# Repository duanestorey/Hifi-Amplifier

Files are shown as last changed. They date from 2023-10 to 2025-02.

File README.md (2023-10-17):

# Hifi-Amplifier
A Custom 5.1 LM3886 Based Custom Amplifier.  The LM3886 has a somewhat mythical status ever since a $3,000 gaincard was released in 1999.  It had amazing sound quality, but inside was only a tweaked LM3886 Texas Instrument 68W amplifier IC.  Since then, an entire community has evolved around these 'gainclones', which truly are hi-fidelity.  This project uses 5 of these, along with a Dolby Decoder IC, to create a complete DIY hi-fidelity 5.1 system.

A breakdown of the directory structure is as follows:

* PCBs - Each of the required PCBs in detail
* Code/ESP32 - The main amplifier code, written to run on an ESP32 WROOM 32 processor  - currently a work in progress and incomplete as the code has recently been changed from a STM32

# Design Philosophy

## PCBs

After iterations over several months to determine PCB usefulness and sizes, most PCBs now utilize a 55mmx55mm size.  This is under the minimum of 100mmx100mm low-cost options 
at several of the large-scale PCB manufacturing sites, and allows useful stacking of PCBs within the chassis.

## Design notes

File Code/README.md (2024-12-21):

### Code

The primary code for the amplifier uses the Espressif IDF framework for the ESP32 chip. 

The DSP routines were coded using the CubeIDE and framework for the STM32 devices.

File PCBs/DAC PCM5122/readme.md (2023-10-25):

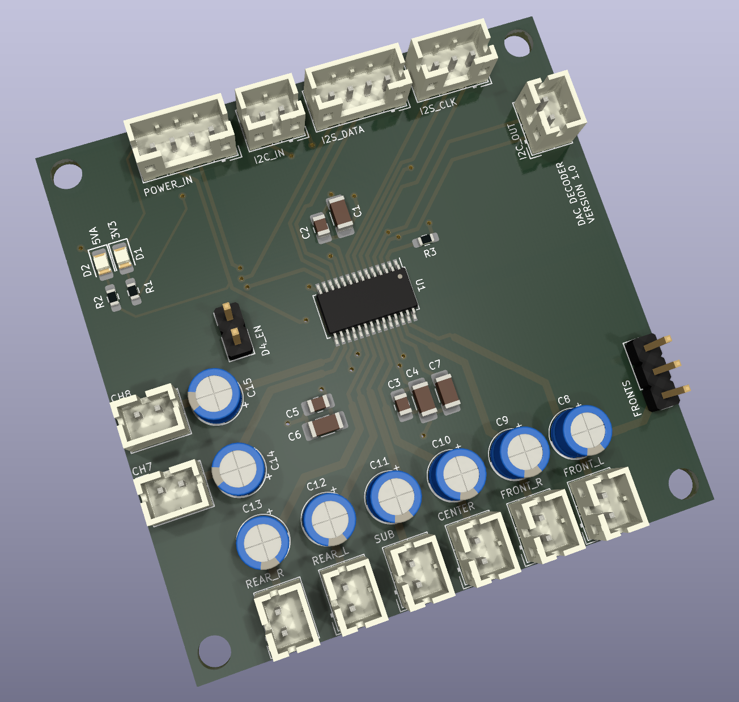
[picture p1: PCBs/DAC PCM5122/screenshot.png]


# Digital To Analog Converter

This PCB is based on the 8 channel Burr Brown PCM1681 IC.  It converts the I2S streams from the Dolby Digital Decoder PCB into 5.1 channel audio for the amplifier.

## Power Connections

### Input 

1. 4-pin GND, 3V3, AGND, 5VA digital/analog

## Version History

- 1.0: Initial Release
- 1.1: Improved Routing

## To Do:

- 1.2: 
    * Add missing address selection pin
    * Impedence match I2S lines

## Speciality Components

* PCM1681 Burr Brown DAC
* Nichicon Muse ES 25V 10uF bi-polar capacitors

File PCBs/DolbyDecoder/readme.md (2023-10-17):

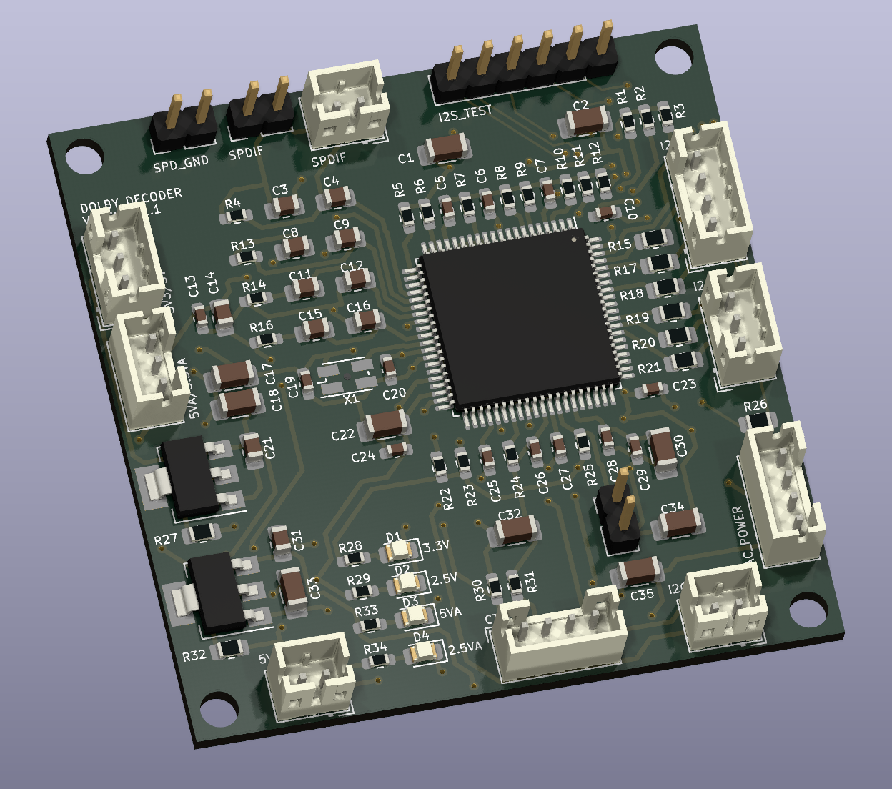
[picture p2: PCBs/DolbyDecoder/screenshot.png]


# Dolby Digital Decoder

This PCB decodes a SPDIF Dolby Digital 5.1 or PCM stream.  It is based on the STA310 set-top box Dolby Digital Decoding IC.

## Speciality Components

* STA310 Dolby Digital Decoding IC
* 27 MHz Clock
* 2.5V 3-pin regulators

## Power Connections

### Input 

1. 3-pin GND, 3V3, 5V digital
2. 3-pin AGND, 3V3A, 5VA analog

### Output

1. 2-pin GND, 5V digital
2. 4-pin GND, 3V3, AGND, 5VA combined digital/analog

## Version History

- 1.0: 
    * Initial Release
- 1.1: 
    * Routed I2S_D0 from Dolby Digital (which is two channel Dolby) to the DAC I2S_D4 pin
    * Re-annotated geographically

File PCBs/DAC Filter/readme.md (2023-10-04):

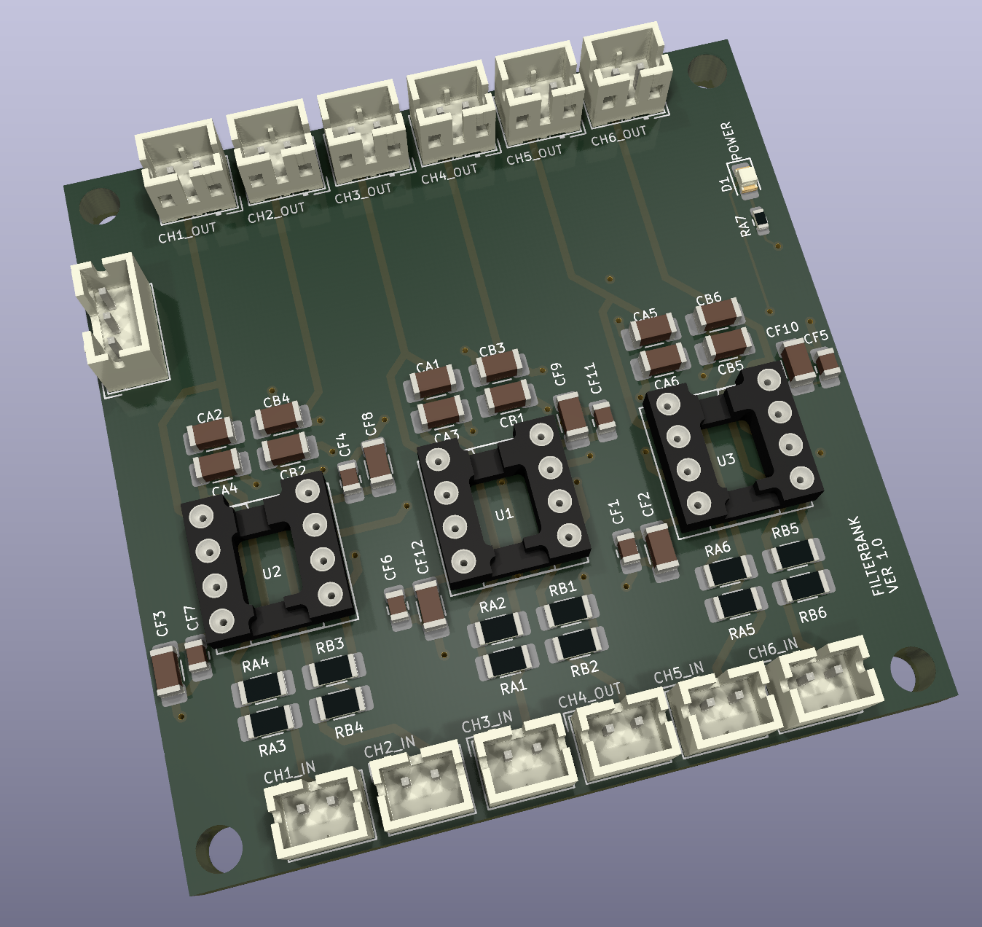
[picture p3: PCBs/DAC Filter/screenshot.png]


# DAC Filters

The output from the DAC board contains some residual noise that needs to be filtered out, which is the purpose of this board.  It utilizes three dual op-amps 
set up as active filters, one for each channel. 

## Power Connections

### Input 

1. 3-pin V-, AGND, V+

## Version History

- 1.0: Initial Release

## Speciality Components

* OPA2134 Burr Brown operation op-amps or equivalents
* 300pF and 30pF C0G 1206 capacitors
* 7.5K and 130K thin film 1206 capacitors

## Filter Design

Texas Instruments recommends a simple first order active Sallen Key filter to reduce the level of post-DAC noise in the audio stream.

I used an online filter designer, setting a 0.2dB drop at 24kHz, with a stopband of -11.5dB at 100kHz.  These were chosen iteratively to try and keep the passband
relatively flat, and the gain as large as possible while still being a second order filter.  The final design has a 3dB corner frequency of 53.7kHz.

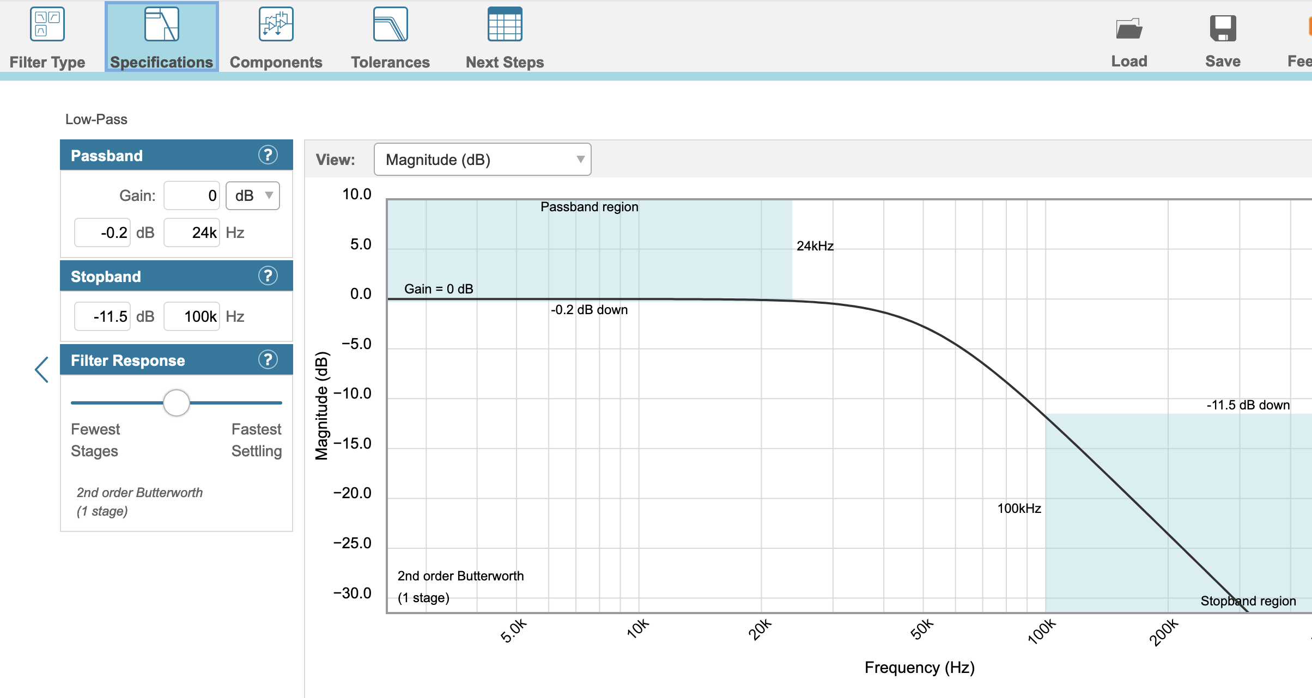
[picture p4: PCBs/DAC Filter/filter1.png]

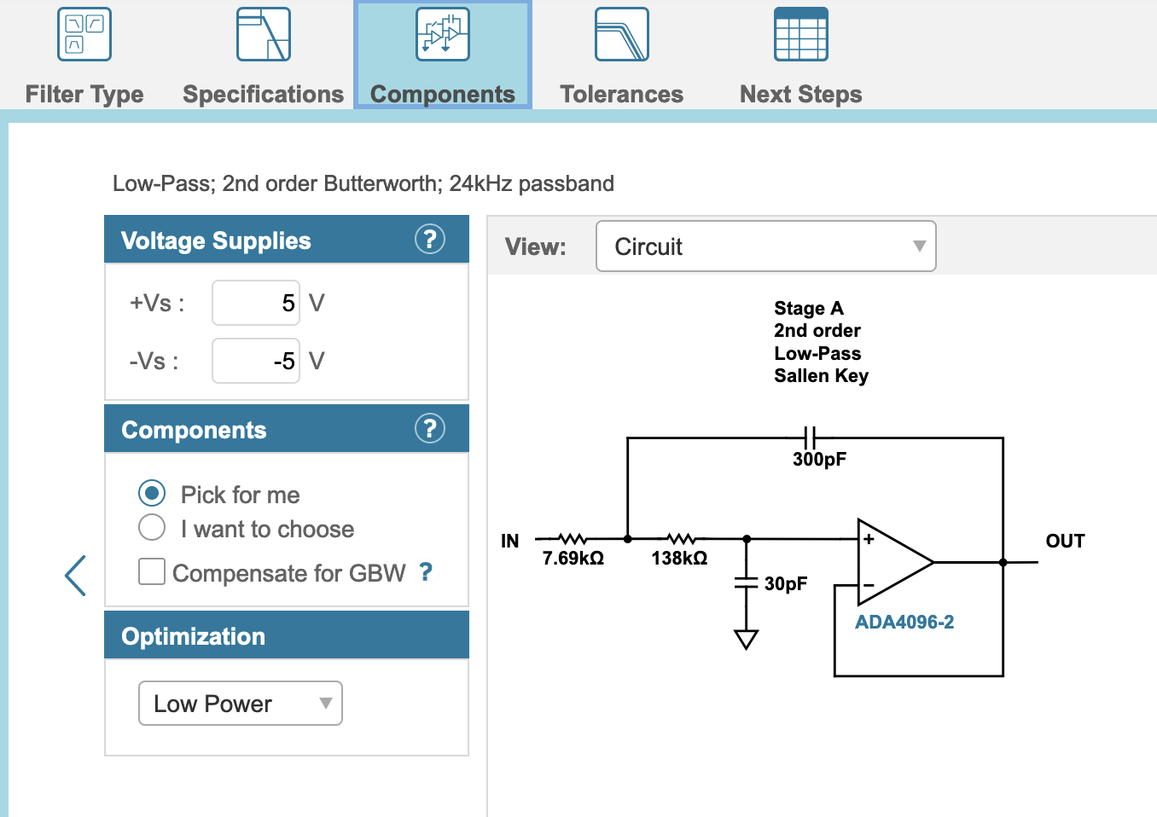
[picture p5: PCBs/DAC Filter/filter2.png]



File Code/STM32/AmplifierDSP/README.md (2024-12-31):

## DSP Code

This code is for a four channel digital signal processor for my Hi-Fi Amplifier.  It will process one stereo input channel and create three 
separate I2S digital audio output channels after processing each using biquad filters.

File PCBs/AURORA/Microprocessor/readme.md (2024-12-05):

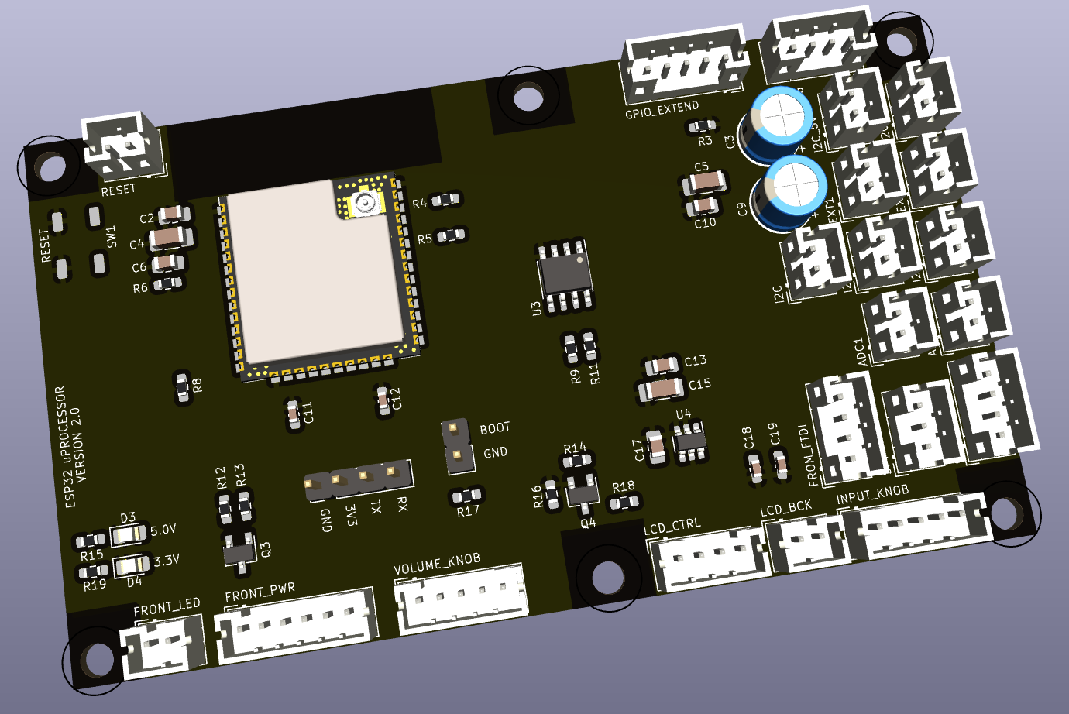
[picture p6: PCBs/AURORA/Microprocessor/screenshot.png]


# Microprocessor Board

The heart of the amplifier is this microprocessor board based on the ESP32 WROOM 32 IC. Now supports a HAT.

## Version History

- 1.0: Initial Release
- 1.1: Addressed issue with ESP32 programming transistors
- 1.2: Added missing pull-down resistor for relay/softstart 

## Speciality Components

* ESP32 WROOM 32
* FT232RL USB to UART converter
* TMP100 temperature sensor

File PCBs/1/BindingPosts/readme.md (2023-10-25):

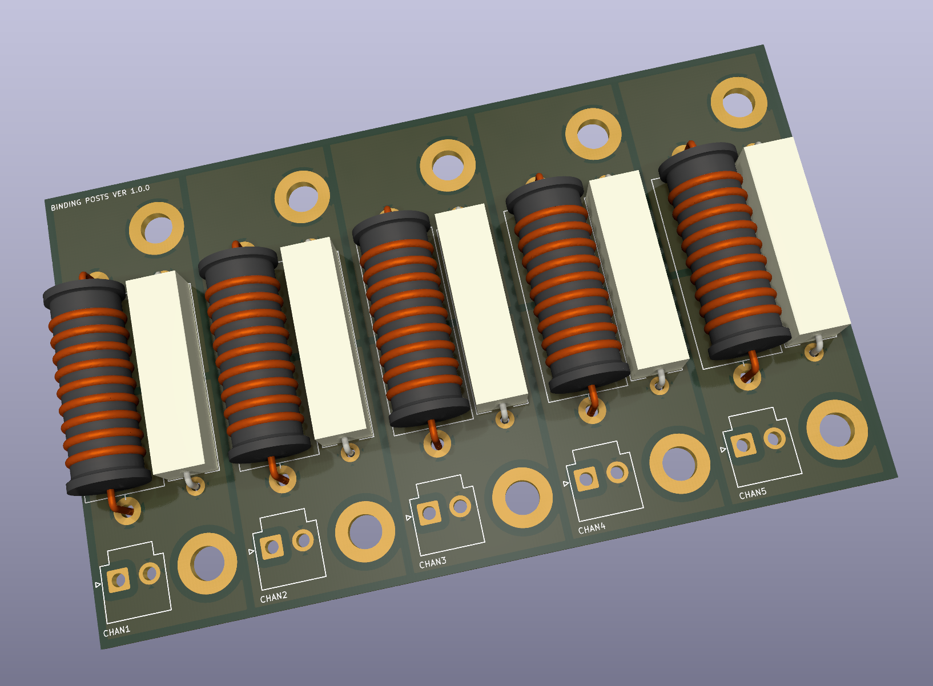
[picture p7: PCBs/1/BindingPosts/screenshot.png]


# Binding Posts

## Version History

- 1.0: Initial Release
- 1.1: First attempt at speaker protection relays

## Speciality Components

* 0.7uH air-core hand-wound inductors
* 5W resistors

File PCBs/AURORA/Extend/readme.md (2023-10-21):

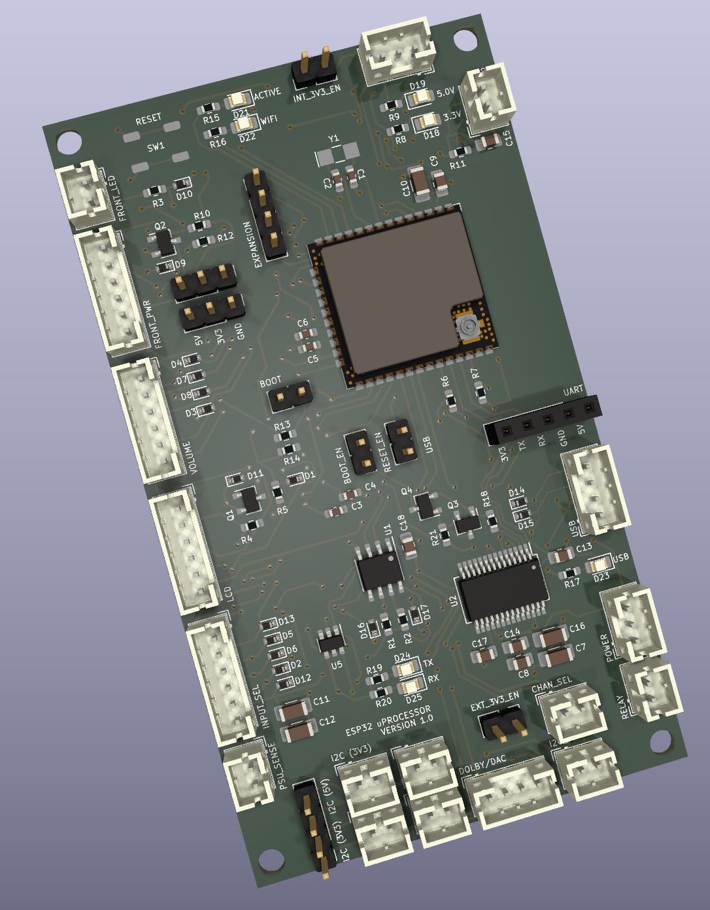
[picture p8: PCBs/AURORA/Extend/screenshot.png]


# Microprocessor Board

The heart of the amplifier is this microprocessor board based on the ESP32 WROOM 32 IC.

## Version History

- 1.0: Initial Release
- 1.1: Addressed issue with ESP32 programming transistors
- 1.2: Added missing pull-down resistor for relay/softstart 

## Speciality Components

* ESP32 WROOM 32
* FT232RL USB to UART converter
* TMP100 temperature sensor

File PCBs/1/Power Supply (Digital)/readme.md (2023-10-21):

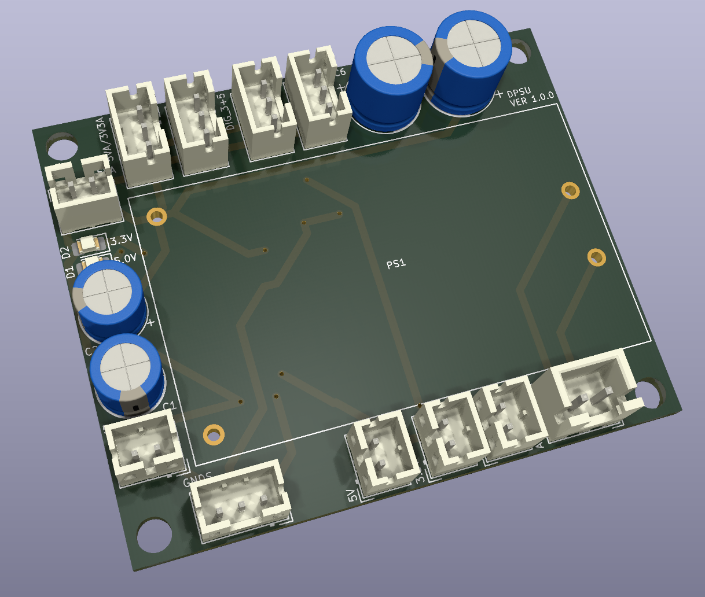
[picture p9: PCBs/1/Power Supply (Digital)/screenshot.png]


# Digital Power Supply

## Version History

- 1.0: Initial Release
- 1.1: Reduced capacitance, added additional connectors

## Speciality Components

* HLK-10M05 5V 10W power supply
* 3.3V regulator

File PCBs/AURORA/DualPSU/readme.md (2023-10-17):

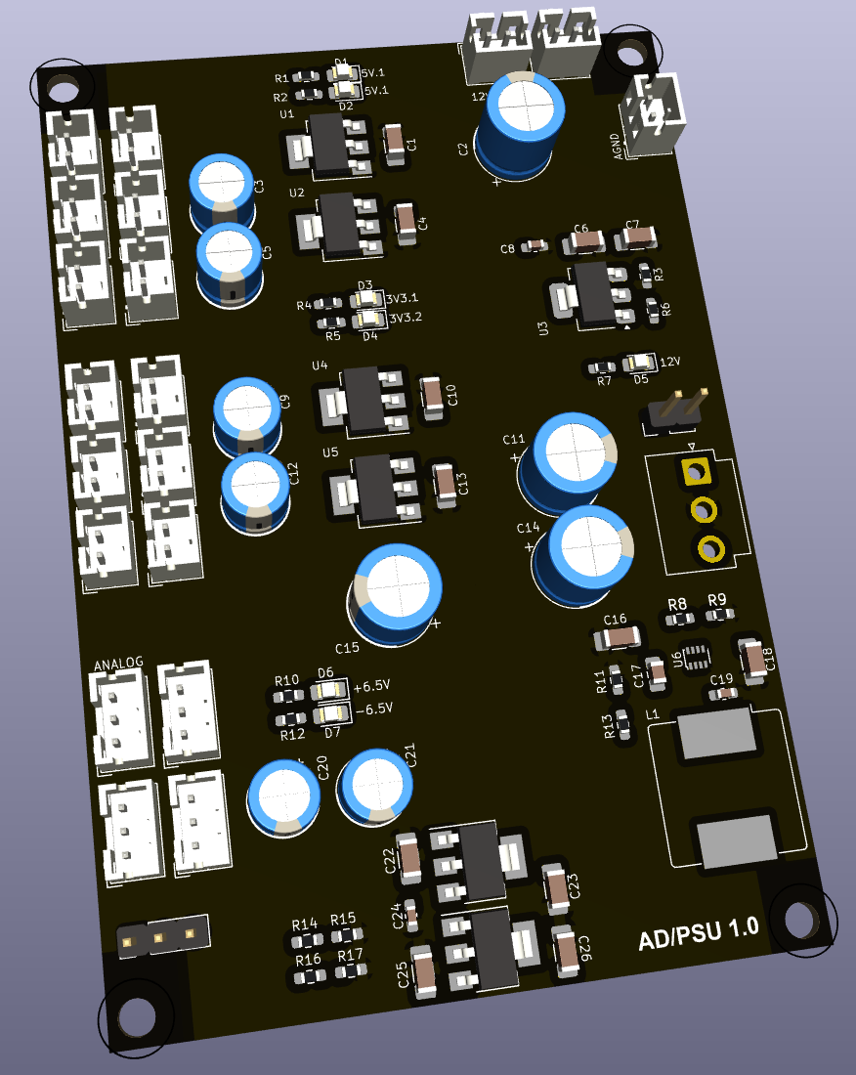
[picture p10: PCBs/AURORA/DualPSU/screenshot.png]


# Analog Power Supply for Operation Amplifier

This board produces a +/- 6.5V supply to be used with the DAC filter and the phono RIAA/pre-amplifier PCBs

## Version History

- 1.0: Initial Release

## Speciality Components

* LM317 & LM337 variable voltage regulators
* Myrra 44091 1.5VA with dual 6V secondaries

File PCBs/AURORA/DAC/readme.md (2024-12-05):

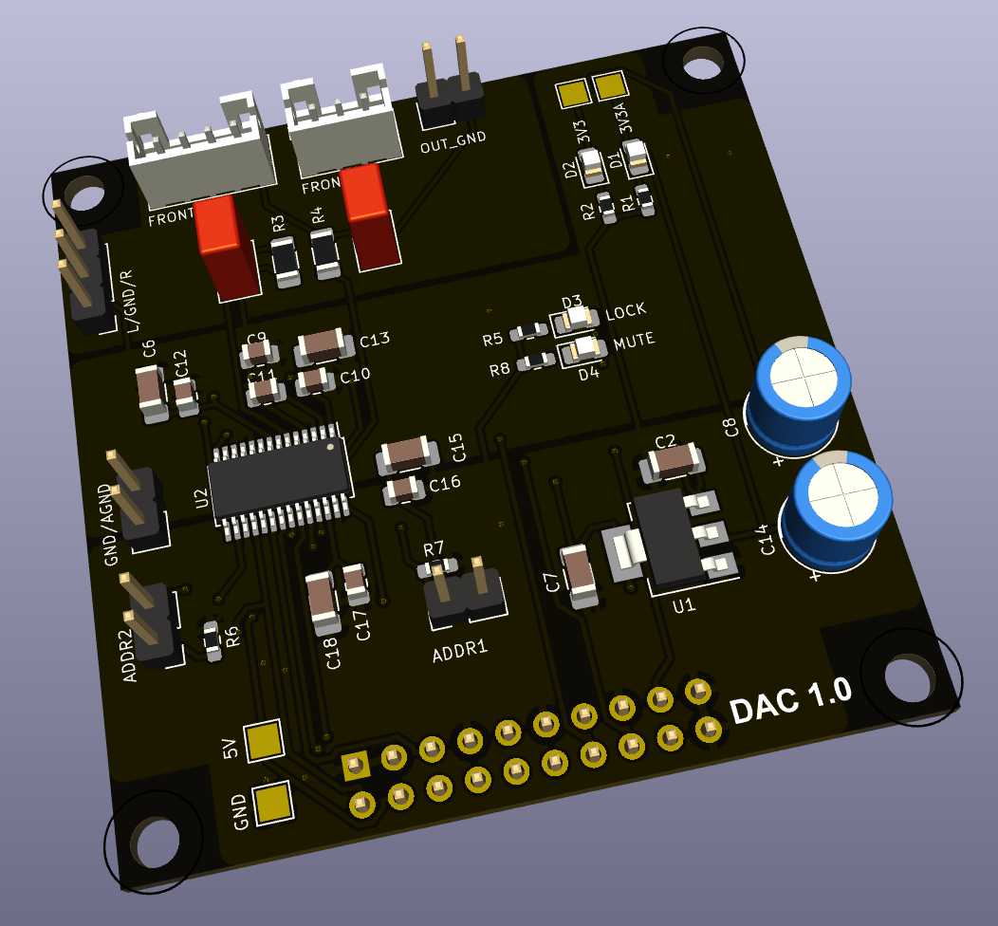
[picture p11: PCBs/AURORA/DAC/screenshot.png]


## DAC 

### Version History

- 1.0: Initial Release

## #Speciality Components

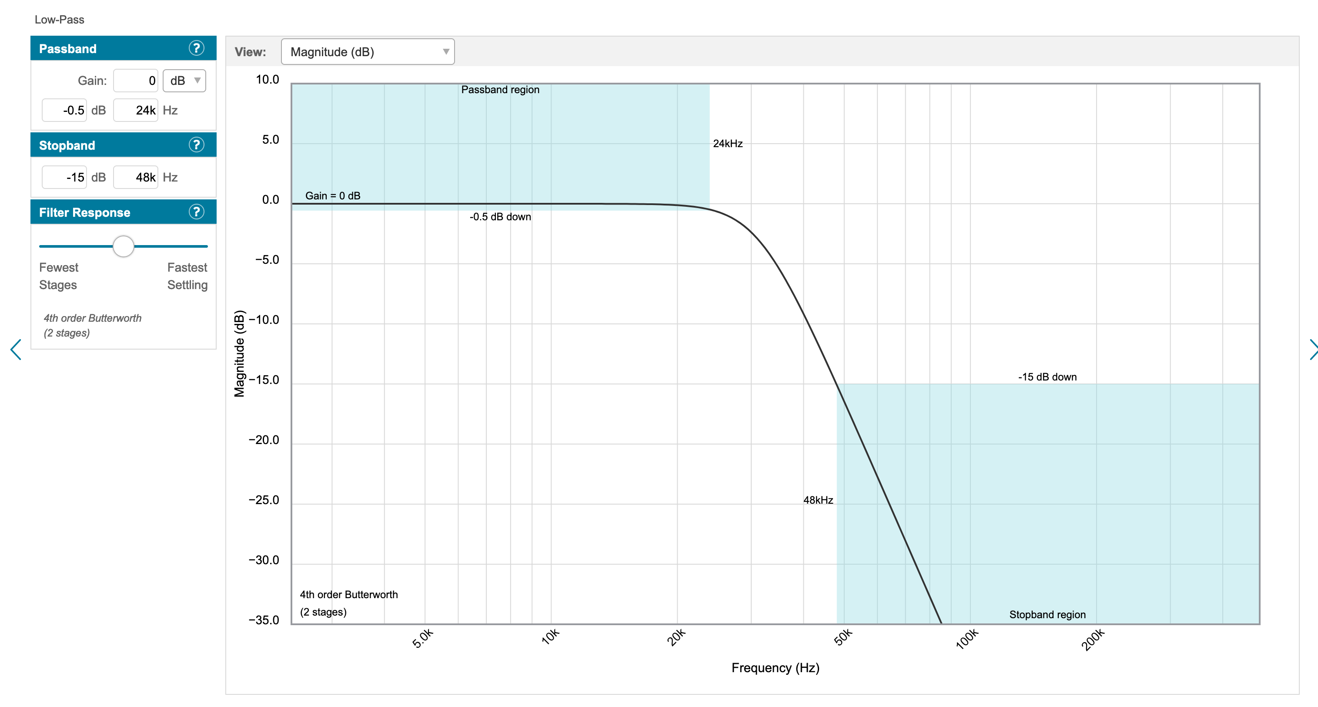
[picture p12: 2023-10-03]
PCBs/DAC Filter/1.1/Filter Design/Screenshot 2023-09-28 at 11.56.09 AM.png

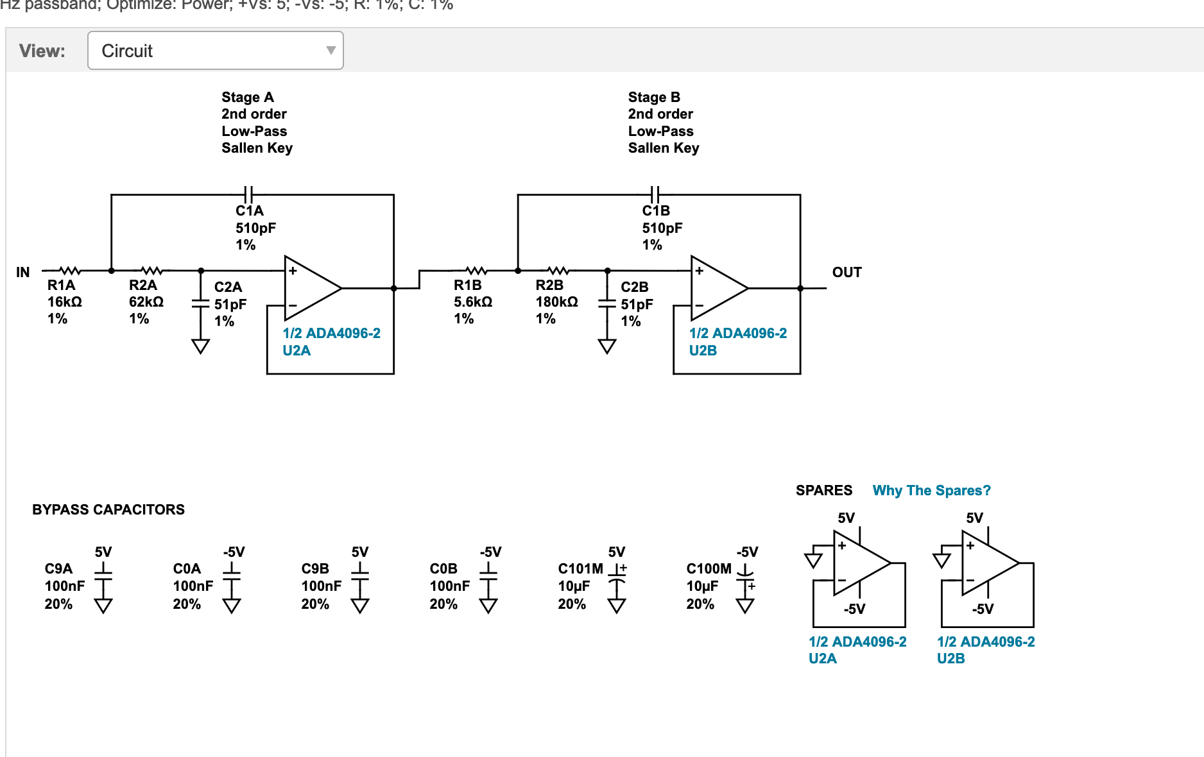
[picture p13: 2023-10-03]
PCBs/DAC Filter/1.1/Filter Design/Screenshot 2023-09-28 at 11.56.31 AM.png

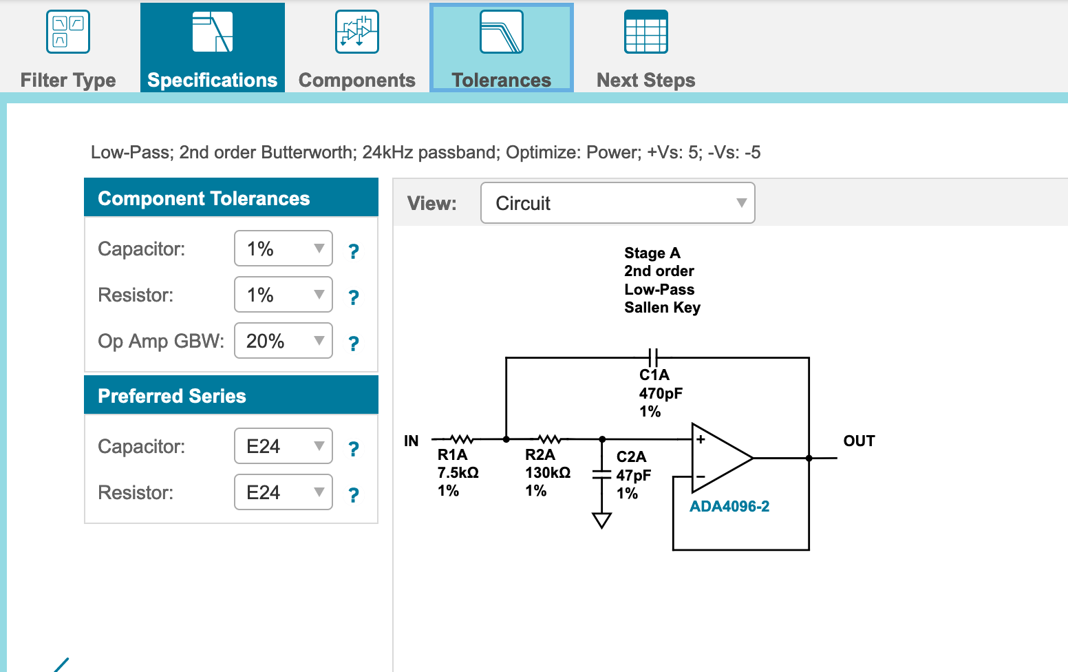
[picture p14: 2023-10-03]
PCBs/DAC Filter/1.1/Filter Design/filter3.png

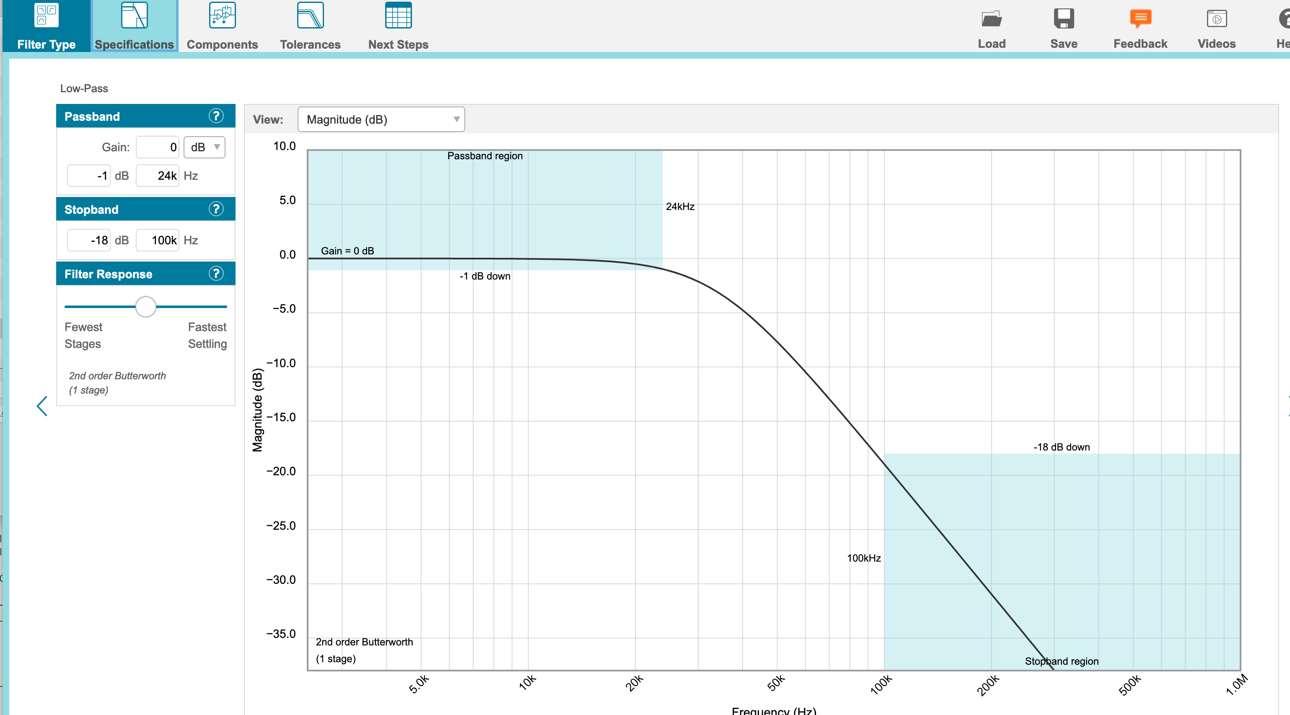
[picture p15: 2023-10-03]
PCBs/DAC Filter/1.1/Filter Design/filter1.png

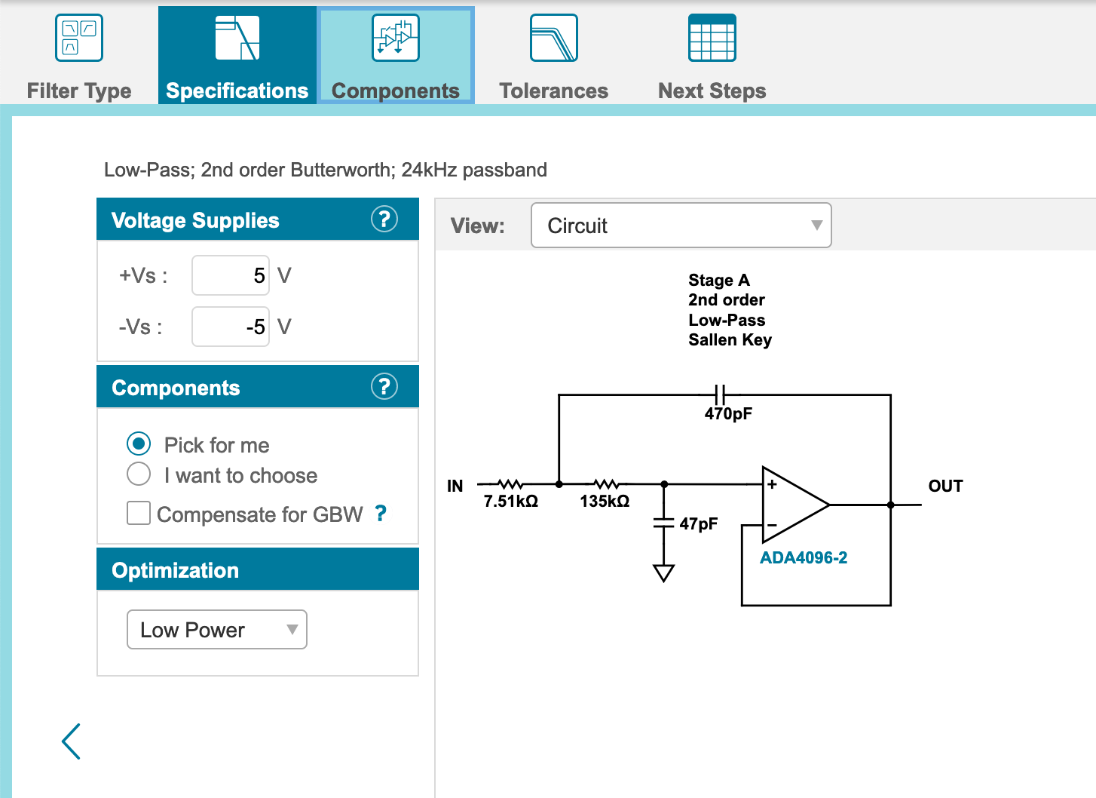
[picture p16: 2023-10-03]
PCBs/DAC Filter/1.1/Filter Design/filter2.png

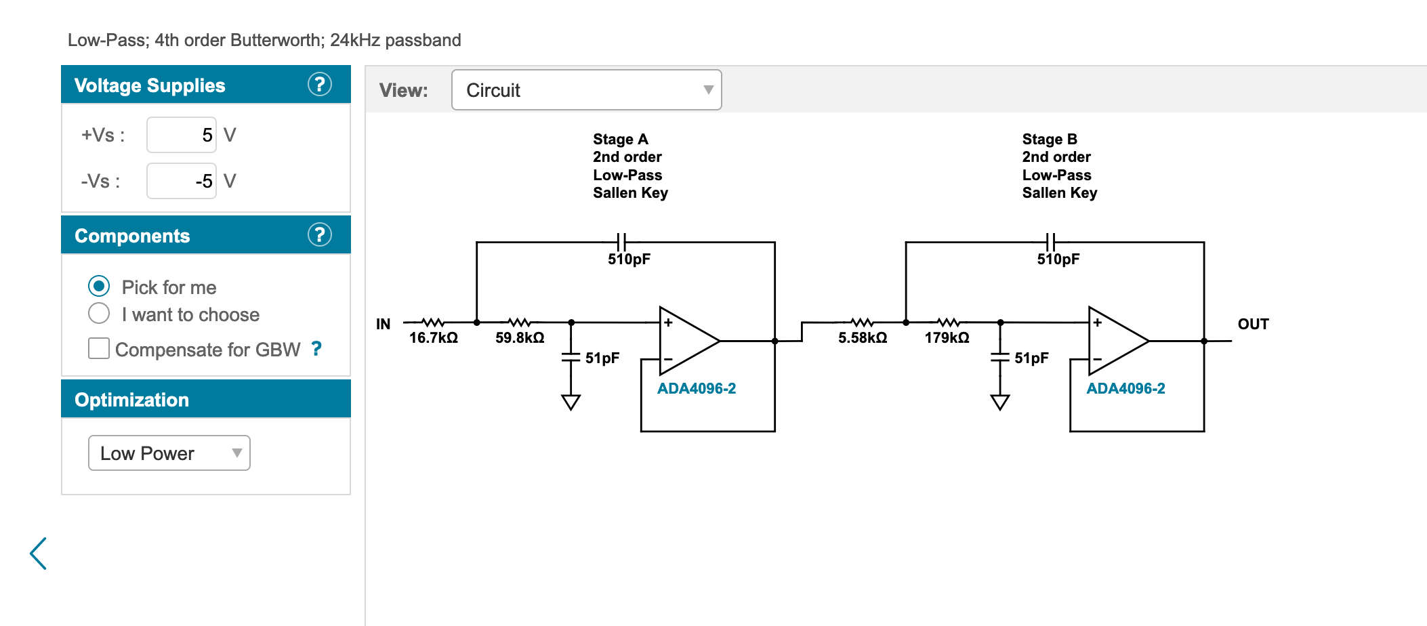
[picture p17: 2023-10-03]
PCBs/DAC Filter/1.1/Filter Design/Screenshot 2023-09-28 at 11.56.17 AM.png

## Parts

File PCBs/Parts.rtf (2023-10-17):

* Generic

50V 0.1uF X7R 603 - ORDERING
100V 0.1uF X7R 805 - YES
25V 10uF X7R 805 - ORDERING
50V 0.1uF X7R 1206 - ORDERING
50V 10uF X7R 1206 - YES
603 1K - YES

* Main PSU
1206 0.036R
612 0.050R
2512 - 1.2K
2512 - R050

* Channel Amp
1k resistor
1.2k resistor - ORDERED
38.6k resistor
20k resistor - YES
10U 1206
100N 805
1000U 12x5P 50V
47U 6.3x2.5 50V
4.7U X7R 50V
200N WIMA 18x7
680p silver mica
47p silver mica
47uF 50V - Mute Red

* Channel Selector
22uf bipolar 5x11

* DAC filter
7.5k 1206 - YES
130k 1206 - YES
300p 1206 C0G - YES
30p 1206 C0G - YES
Future Multiple feedback -
3.6k 1206, - ordered
1.2nF 1206 C0G - ordered ?
1k 1206 - ordered
18k 1206 - ordered
2.2nF 1206 C0G - ordered
220pF 2106 C0G

* Dolby Decoder
75R 603 1 - YES
47R 603 6 - YES
4.7K 603 13 - YES
430R 603 1 - ORDERED
160R 603 2- ORDERED
330R 603 1 - - ORDERED
47U/22U/10U 1206
0.1U 603
10U 805
10U 1206
10N 603
100N 803
470P 805 - YES
5.6N 805 - YES
150P 805 - YES
4.7N 805 - YES
22R 805 - - ORDERED
47R 805 - - ORDERED
27MHz - - YES

* Vinyl Pre-amp
1uf bipolar 5x11
22uf bipolar 5x11
10uf bipolar 5x11
180k 805 - ORDERED
4.7k 805 - ORDERED
750R 805 - ORDERED
100k 805 - ORDERED
2.7K 805 - ORDERED
2.2K 805 - ORDERED
100K 805 - ORDERED
47K 805 - - ORDERED
0.1uf 1206 C0G - ORDERED
220U 16V - 6.3x2.5 - ORDERED, NOUSER

Rectifier
100nF Wima 13x6 220VAC - YES

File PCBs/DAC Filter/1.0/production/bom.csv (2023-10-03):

Designator | Footprint | Quantity | Value | LCSC Part #
CA1, CA2, CA5, CB3, CB4, CB6 | C_1206_3216Metric_Pad1.33x1.80mm_HandSolder | 6 | 470P
CA3, CA4, CA6, CB1, CB2, CB5 | C_1206_3216Metric_Pad1.33x1.80mm_HandSolder | 6 | 47P
CF1, CF11, CF4, CF5, CF6, CF7 | C_0805_2012Metric_Pad1.18x1.45mm_HandSolder | 6 | 0.1u
CF10, CF12, CF2, CF3, CF8, CF9 | C_1206_3216Metric_Pad1.33x1.80mm_HandSolder | 6 | 10u
D1 | LED_0805_2012Metric_Pad1.15x1.40mm_HandSolder | 1 | YELLOW
H1, H2, H3, H4 | MountingHole_3.2mm_M3 | 4 | MountingHole
J10, J11, J12, J13, J14, J2, J3, J5, J6, J7, J8, J9 | JST_PH_B2B-PH-K_1x02_P2.00mm_Vertical | 12 | Conn_01x02_Male
J4 | JST_PH_B3B-PH-K_1x03_P2.00mm_Vertical | 1 | Conn_01x03_Male
RA1, RA3, RA5, RB2, RB4, RB6 | R_1206_3216Metric_Pad1.30x1.75mm_HandSolder | 6 | 7.5K
RA2, RA4, RA6, RB1, RB3, RB5 | R_1206_3216Metric_Pad1.30x1.75mm_HandSolder | 6 | 130K
RA7 | R_0603_1608Metric | 1 | 7.5K
U1, U2, U3 | DIP-8_W7.62mm_Socket | 3 | OPA2134

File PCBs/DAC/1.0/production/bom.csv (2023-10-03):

Designator | Footprint | Quantity | Value | LCSC Part #
C1, C4, C6, C7 | C_1206_3216Metric_Pad1.33x1.80mm_HandSolder | 4 | 10U
C10, C11, C12, C13, C14, C15, C8, C9 | CP_Radial_D5.0mm_P2.00mm | 8 | 10U
C2, C3, C5 | C_0805_2012Metric_Pad1.18x1.45mm_HandSolder | 3 | 100N
D1, D2 | LED_0805_2012Metric_Pad1.15x1.40mm_HandSolder | 2 | YELLOW
H1, H2, H3, H4 | MountingHole_3.2mm_M3 | 4 | MountingHole
J1, J11, J12, J15, J2, J3, J4, J5, J6, J7 | JST_PH_B2B-PH-K_1x02_P2.00mm_Vertical | 10 | Conn_01x02_Male
J10, J9 | JST_PH_B4B-PH-K_1x04_P2.00mm_Vertical | 2 | Conn_01x04_Male
J13 | PinHeader_1x03_P2.54mm_Vertical | 1 | Conn_01x03_Male
J14 | PinHeader_1x02_P2.54mm_Vertical | 1 | Conn_01x02_Male
J8 | JST_PH_B3B-PH-K_1x03_P2.00mm_Vertical | 1 | Conn_01x03_Male
R1 | R_0603_1608Metric_Pad0.98x0.95mm_HandSolder | 1 | 430R
R2 | R_0603_1608Metric_Pad0.98x0.95mm_HandSolder | 1 | 1K
R3 | R_0603_1608Metric_Pad0.98x0.95mm_HandSolder | 1 | 4.7K
U1 | HTSSOP-28-1EP_4.4x9.7mm_P0.65mm_EP3.4x9.5mm_Mask2.4x6.17mm_ThermalVias | 1 | PCM1681

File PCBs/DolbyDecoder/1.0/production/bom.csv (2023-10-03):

Designator | Footprint | Quantity | Value | LCSC Part #
C1, C17, C4, C7 | C_1206_3216Metric_Pad1.33x1.80mm_HandSolder | 4 | 47U
C10, C12, C13, C14, C15, C16, C19, C20, C21, C22, C25, C8, C9 | C_0603_1608Metric_Pad1.08x0.95mm_HandSolder | 13 | 0.1U
C11, C24, C5 | C_0805_2012Metric_Pad1.18x1.45mm_HandSolder | 3 | 10U
C18, C2, C3, C34, C35, C6 | C_1206_3216Metric_Pad1.33x1.80mm_HandSolder | 6 | 10U
C23 | C_0603_1608Metric_Pad1.08x0.95mm_HandSolder | 1 | 10N
C26, C27 | C_0805_2012Metric_Pad1.18x1.45mm_HandSolder | 2 | 100N
C28, C30 | C_0805_2012Metric_Pad1.18x1.45mm_HandSolder | 2 | 470P
C29, C31 | C_0805_2012Metric_Pad1.18x1.45mm_HandSolder | 2 | 5.6N
C32 | C_0805_2012Metric_Pad1.18x1.45mm_HandSolder | 1 | 150P
C33 | C_0805_2012Metric_Pad1.18x1.45mm_HandSolder | 1 | 4.7N
D1, D2, D4 | LED_0805_2012Metric_Pad1.15x1.40mm_HandSolder | 3 | YELLOW
D3 | LED_0805_2012Metric_Pad1.15x1.40mm_HandSolder | 1 | ORANGE
H1, H2, H3, H4 | MountingHole_3.2mm_M3 | 4 | MountingHole
J1, J11, J2 | JST_PH_B3B-PH-K_1x03_P2.00mm_Vertical | 3 | Conn_01x03_Male
J10, J13, J4 | JST_PH_B4B-PH-K_1x04_P2.00mm_Vertical | 3 | Conn_01x04_Male
J12 | PinHeader_1x06_P2.54mm_Vertical | 1 | Conn_01x06_Male
J3 | PinHeader_1x02_P2.54mm_Vertical | 1 | Conn_01x02
J5, J6, J7 | JST_PH_B2B-PH-K_1x02_P2.00mm_Vertical | 3 | Conn_01x02_Male
J8, J9 | PinHeader_1x02_P2.54mm_Vertical | 2 | Conn_01x02_Male
R1, R2 | R_0805_2012Metric_Pad1.20x1.40mm_HandSolder | 2 | 22R
R10, R12, R14, R16, R17, R20, R24, R3, R4, R5, R7, R8, R9 | R_0603_1608Metric_Pad0.98x0.95mm_HandSolder | 13 | 4.7K
R11, R13, R15, R6 | R_0603_1608Metric_Pad0.98x0.95mm_HandSolder | 4 | 10K
R18 | R_0603_1608Metric_Pad0.98x0.95mm_HandSolder | 1 | 75R
R19, R21, R26, R29, R30, R31 | R_0805_2012Metric_Pad1.20x1.40mm_HandSolder | 6 | 47R
R22, R23, R33 | R_0603_1608Metric_Pad0.98x0.95mm_HandSolder | 3 | 1K
R25 | R_0603_1608Metric_Pad0.98x0.95mm_HandSolder | 1 | 430R
R27, R28 | R_0603_1608Metric_Pad0.98x0.95mm_HandSolder | 2 | 160R
R32 | R_0603_1608Metric_Pad0.98x0.95mm_HandSolder | 1 | 330R
U1, U2 | SOT-223 | 2 | AMS1117-2.5
U3 | LQFP-80_14x14mm_P0.65mm | 1 | SPA130
X1 | Oscillator_SMD_EuroQuartz_XO32-4Pin_3.2x2.5mm_HandSoldering | 1 | TXC-7C

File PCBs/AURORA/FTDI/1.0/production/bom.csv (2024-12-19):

Designator | Footprint | Quantity | Value | LCSC Part #
C1, C5, C6, C8 | 1206 | 4 | 10U
C10, C11 | CP_Radial_D6.3mm_P2.50mm | 2 | 470u
C2, C3, C4, C7, C9 | 0805 | 5 | 0.1U
D1, D3 | 0603 | 2 | BLUE | XL-1608UBC-04
D2 | 0603 | 1 | YELLOW | XL-1608UBC-04
H1, H2, H3, H4 | MountingHole_3.2mm_M3_DIN965_Pad_TopOnly | 4 | MountingHole
J1, J2 | JST_PH_B4B-PH-K_1x04_P2.00mm_Vertical | 2 | Conn_01x04_Pin
J5 | JST_PH_B3B-PH-K_1x03_P2.00mm_Vertical | 1 | Conn_01x03_Pin
Q1, Q2 | TSOT-23 | 2 | 2N3055
R1 | 0603 | 1 | 100R
R2 | 0603 | 1 | 430R
R3, R4 | 0603 | 2 | 10K
R5 | 0603 | 1 | 150R
U1 | SSOP-28_5.3x10.2mm_P0.65mm | 1 | FT232RL
U2 | SOIC-16W_7.5x10.3mm_P1.27mm | 1 | ADUM3160

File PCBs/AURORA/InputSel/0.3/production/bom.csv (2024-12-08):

Designator | Footprint | Quantity | Value | LCSC Part #
C1, C17, C18, C4 | CP_Radial_D6.3mm_P2.50mm | 4 | 470u
C11, C13, C5 | 0805 | 3 | 0.1U
C15, C16, C2 | 1206 | 3 | 10U
H1, H2, H3, H4 | MountingHole_3.2mm_M3 | 4 | MountingHole
J1, J15, J17, J18, J2, J3, J4, J5, J6, J9 | JST_PH_B3B-PH-K_1x03_P2.00mm_Vertical | 10 | Conn_01x03_Pin
J13 | JST_PH_B3B-PH-K_1x03_P2.00mm_Vertical | 1 | Conn_01x03_Male
J14 | JST_PH_B2B-PH-K_1x02_P2.00mm_Vertical | 1 | Conn_01x02_Male
J16 | PinHeader_1x02_P2.54mm_Vertical | 1 | Conn_01x02_Pin
J7 | PinHeader_1x02_P2.54mm_Vertical | 1 | Conn_01x02_Male
R1, R2, R3, R4, R5, R6, R7 | 0603 | 7 | 4.7K
U1 | SOIC-28W_7.5x18.7mm_P1.27mm | 1 | MPC507
U4 | SSOP-28_5.3x10.2mm_P0.65mm | 1 | MCP23017_SS

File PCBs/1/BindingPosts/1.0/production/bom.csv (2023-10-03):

Designator | Footprint | Quantity | Value | LCSC Part #
H1, H10, H2, H3, H4, H5, H6, H7, H8, H9 | MountingHole_4.3mm_M4_DIN965_Pad | 10 | MountingHole_Pad
J1, J2, J3, J4, J5 | JST_VH_B2P-VH-B_1x02_P3.96mm_Vertical | 5 | Conn_01x02_Male
L1, L2, L3, L4, L5 | L_Axial_L26.0mm_D10.0mm_P30.48mm_Horizontal_Fastron_77A | 5 | 0.7u
R1, R2, R3, R4, R5 | R_Axial_Power_L25.0mm_W6.4mm_P27.94mm | 5 | 10R

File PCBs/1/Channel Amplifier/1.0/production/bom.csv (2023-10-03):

Designator | Footprint | Quantity | Value | LCSC Part #
C1 | R_1206_3216Metric_Pad1.30x1.75mm_HandSolder | 1 | 10U
C2 | R_0805_2012Metric_Pad1.20x1.40mm_HandSolder | 1 | 10N
C3, C6 | CP_Radial_D12.5mm_P5.00mm | 2 | 1000U 50V
C4, C7, Cm1 | CP_Radial_D6.3mm_P2.50mm | 3 | 47U 50V
C5 | C_Disc_D6.0mm_W4.4mm_P5.00mm | 1 | 4.7U X7R 50V
C8 | C_Disc_D6.0mm_W4.4mm_P5.00mm | 1 | 4.7U X74 50V
CSn1 | C_Rect_L18.0mm_W7.0mm_P15.00mm_FKS3_FKP3 | 1 | 220N PP 100V
Cc1 | C_Disc_D11.0mm_W5.0mm_P10.00mm | 1 | 680P
Cf1 | C_Disc_D9.0mm_W5.0mm_P7.50mm | 1 | 47P
Ci1 | CP_Radial_D16.0mm_P7.50mm | 1 | 1000U 35V
Cin1 | CP_Radial_D5.0mm_P2.00mm | 1 | 10UF
D1 | LED_0805_2012Metric_Pad1.15x1.40mm_HandSolder | 1 | YELLOW
D2 | LED_0805_2012Metric_Pad1.15x1.40mm_HandSolder | 1 | BLUE
H1, H2, H3, H4 | MountingHole_3mm | 4 | MountingHole
J1, J4, J9 | JST_PH_B2B-PH-K_1x02_P2.00mm_Vertical | 3 | Conn_01x02_Male
J2, J3, J7 | PinHeader_1x02_P2.54mm_Vertical | 3 | Conn_01x02_Male
J5 | PinHeader_1x03_P2.54mm_Vertical | 1 | Conn_01x03_Male
J6 | JST_VH_B2P-VH_1x02_P3.96mm_Vertical | 1 | Conn_01x02_Male
J8 | JST_VH_B3P-VH-B_1x03_P3.96mm_Vertical | 1 | Conn_01x03_Male
R1 | R_0603_1608Metric_Pad0.98x0.95mm_HandSolder | 1 | 4.7K
R2 | R_0805_2012Metric_Pad1.20x1.40mm_HandSolder | 1 | 100R
R3, R4 | R_0805_2012Metric_Pad1.20x1.40mm_HandSolder | 2 | 9.1K
R6 | R_Axial_DIN0207_L6.3mm_D2.5mm_P10.16mm_Horizontal | 1 | 1.0K
RB1 | R_Axial_DIN0207_L6.3mm_D2.5mm_P10.16mm_Horizontal | 1 | 1.2K
RSn1 | R_Axial_DIN0411_L9.9mm_D3.6mm_P12.70mm_Horizontal | 1 | 4R7
Rf1, Rf2, Rin1 | R_Axial_DIN0207_L6.3mm_D2.5mm_P10.16mm_Horizontal | 3 | 20K
Rmute1 | R_Axial_DIN0207_L6.3mm_D2.5mm_P10.16mm_Horizontal | 1 | 38.6K
U1 | SOT-23-6 | 1 | TMP100
U2 | TO-220-11_P3.4x5.08mm_StaggerOdd_Lead4.85mm_Vertical | 1 | LM3886

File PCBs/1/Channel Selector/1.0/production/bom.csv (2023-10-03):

Designator | Footprint | Quantity | Value | LCSC Part #
C1, C13, C15, C16, C17, C18, C19, C2, C20, C21, C22, C23, C24, C25, C3, C4, C5, C6, C8, C9 | CP_Radial_D5.0mm_P2.50mm | 20 | 10U
C10 | C_1206_3216Metric_Pad1.33x1.80mm_HandSolder | 1 | 100N C0G
C11, C14 | C_1206_3216Metric_Pad1.33x1.80mm_HandSolder | 2 | 10U
C12 | C_0805_2012Metric_Pad1.18x1.45mm_HandSolder | 1 | 0.1U
C7 | C_1206_3216Metric_Pad1.33x1.80mm_HandSolder | 1 | 47N C0G
D1 | LED_0805_2012Metric_Pad1.15x1.40mm_HandSolder | 1 | YELLOW
H1, H2, H3, H4 | MountingHole_3.2mm_M3 | 4 | MountingHole
J1, J10, J11, J12, J13, J14, J16, J17, J18, J2, J3, J4, J5, J6, J7, J8, J9 | JST_PH_B2B-PH-K_1x02_P2.00mm_Vertical | 17 | Conn_01x02_Male
J15 | JST_PH_B2B-PH-K_1x02_P2.00mm_Vertical | 1 | CTO
R1, R10, R11, R12, R13, R16, R17, R19, R2, R20, R22, R24, R26, R27, R28, R29, R3, R4, R5, R6 | R_0805_2012Metric_Pad1.20x1.40mm_HandSolder | 20 | 100K
R7, R8 | R_0805_2012Metric_Pad1.20x1.40mm_HandSolder | 2 | 24K
R9 | R_0603_1608Metric_Pad0.98x0.95mm_HandSolder | 1 | 1K
U1 | SOIC-28W_7.5x18.7mm_P1.27mm | 1 | AX2358

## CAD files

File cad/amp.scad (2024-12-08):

width = 435;
height = 82;
depth = 311;

margin_lr = 20;


$fn = 64;


difference() {
  cube( [ width, depth, height ] );
            
  translate( [ 2, 2, 2 ] ) {
    cube( [ width - 4, depth - 4, height + 10 ] );
  }
}


// new channel left (blue)
translate( [ 15, depth - margin_lr - 115, 10 ] ) {
  translate( [ 40, 2.5, 0 ] ) {
      cube( [ 55, 95, 4 ] );
  }
  color( "blue" )
  cube( [ 40, 100, 50 ] );   
}

// new channel right (blue)
translate( [ 190, depth - margin_lr - 115, 10 ] ) {
  translate( [ 40, 2.5, 0 ] ) {
      cube( [ 55, 95, 4 ] );
  }
  color( "blue" )
  cube( [ 40, 100, 50 ] );    
}

// adau
translate( [ 130, depth - margin_lr - 115, 10 ] ) {
    color( "pink" )
  cube( [ 45, 95, 4 ] );   
}

// microprocessor
translate( [ margin_lr, margin_lr, 10 ] ) {
  color( "brown" )
  cube( [ 95, 55, 4 ] );   
}

// GPIO extender (pink)
translate( [ margin_lr + 40, margin_lr, 40 ] ) {
  color( "pink" )
  cube( [ 55, 55, 4 ] );   
}

// SPDIF (cyan)
translate( [ margin_lr, margin_lr + 70, 0 ] ) {
    color( "cyan" )
  cube( [ 95, 55, 4 ] );   
}

// DAC (orange)
translate( [ margin_lr + 40, margin_lr + 70, 40 ] ) {
  color( "orange" )
  cube( [ 55, 55, 4 ] );   
}


// subwoofer (magenta)
translate( [ 140, 90, 40 ] ) {
  color( "black" )
  cube( [ 65, 55, 4 ] );   
}


// channel sel (Yellow)
translate( [ 140, margin_lr + 70, 10 ] ) {
  color( "yellow" )
  cube( [ 65, 55, 4 ] );   
}

// vinyl (RED)
translate( [ 140, margin_lr, 40 ] ) {
  color( "red" )
  cube( [ 65, 55, 4 ] );   
}

// digital/ananlog power suppy
translate( [ 230, margin_lr, 10 ] ) {
  color( "Lavender" )
  cube( [ 65, 95, 4 ] );   
}
    
// FTDI
translate( [ 140, margin_lr, 10 ] ) {
  color( "purple" )
  cube( [ 65, 55, 4 ] );   
}
    

// power suppy
translate( [ width - margin_lr - 95, margin_lr, 10 ] ) {
  cube( [ 95, 95, 4 ] );   
}

// ground lift (green)
translate( [ width - margin_lr - 65, 130, 10 ] ) {
  color( "green" )
  cube( [ 65, 35, 4 ] );   
}


// toroid
translate( [ width - margin_lr - 95, depth - 135, 0 ] ) {
  cube( [ 95, 95, 45] );   
}
       

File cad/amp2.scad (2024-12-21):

width = 435;
height = 82;
depth = 311;

margin_lr = 20;

$fn = 64;

difference() {
  cube( [ width, depth, height ] );
            
  translate( [ 2, 2, 2 ] ) {
    cube( [ width - 4, depth - 4, height + 10 ] );
  }
}

// Column One 

// PCM5142/DAC
translate( [ margin_lr, 220 + margin_lr - 10, 10 ] ) {
  color( "black" )
  cube( [ 85, 55, 4 ] );   
}

// DSP
translate( [ margin_lr, 150 + margin_lr - 10, 10 ] ) {
  color( "orange" )
  cube( [ 85, 55, 4 ] );   
}


/*
// I2S board (violet)
translate( [ margin_lr, margin_lr + 70, 30 ] ) {
  color( "violet" )
  cube( [ 85, 55, 4 ] );   
}
*/


/*
// subwoofer
translate( [ margin_lr, margin_lr + 210, 10 ] ) {
    color( "pink" )
  cube( [ 85, 55, 4 ] );   
}
*/

// SPDIF (cyan)
translate( [ margin_lr, margin_lr + 70, 10 ] ) {
    color( "cyan" )
  cube( [ 85, 55, 4 ] );   
}


// microprocessor
translate( [ margin_lr, margin_lr, 10 ] ) {
  color( "brown" )
  cube( [ 85, 55, 4 ] );   
}



// Column Two

// vinyl (RED)
translate( [ 120, margin_lr + 70, 10 ] ) {
  color( "red" )
  cube( [ 85, 55, 4 ] );   
}

// ADC board (indigo)
translate( [ 120, margin_lr + 70, 30 ] ) {
  color( "indigo" )
  cube( [ 85, 55, 4 ] );   
}


// inputs (grey)
translate( [ 120, margin_lr + 210, 10 ] ) {
  color( "grey" )
  cube( [ 85, 55, 4 ] );   
}

// channel sel (Yellow)
translate( [ 120, margin_lr + 140, 10 ] ) {
  color( "yellow" )
  cube( [ 85, 55, 4 ] );   
}

// GPIO extender (blue)
translate( [ margin_lr + 100, margin_lr, 30 ] ) {
  color( "#000080" )
  cube( [ 85, 55, 4 ] );   
}

// FTDI (purple)
translate( [ margin_lr + 100, margin_lr, 10 ] ) {
  color( "purple" )
  cube( [ 85, 55, 4 ] );   
}

// POWER ROW

// digital/ananlog power suppy
translate( [ 240, margin_lr, 10 ] ) {
  color( "Lavender" )
  cube( [ 65, 95, 4 ] );   
}
    
// power suppy
translate( [ width - margin_lr - 95, margin_lr, 10 ] ) {
  cube( [ 95, 95, 4 ] );   
}

// rectifier (pink)
translate( [ width - margin_lr - 35, depth - 160 - margin_lr, 10 ] ) {
  color( "pink" )
  cube( [ 35, 65, 4 ] );   
}

// ground lift (green)
translate( [ width - margin_lr - 35, depth - 80 - margin_lr, 10 ] ) {
  color( "green" )
  cube( [ 35, 65, 4 ] );   
}



// toroid
translate( [ width - margin_lr - 180, depth - margin_lr - 10 -130, 0 ] ) {
  cube( [ 124, 124, 41 ] );   
}
       

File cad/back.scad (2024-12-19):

width = 433;
height = 80;
depth = 1;

margin_lr = 20;

$fn = 64;


rca_dist = 18;

offset = 30;
y2 = 25;
y1 = y2 + offset;

y_mid = 40;

subwoofer_input_x = 30;
spdif_input_x = 60;
xlr_input_x = 230;
rca_input_x = 110;
usb_input_x = 410;

reset_size = 4;
usb_size = 10;
xlr_size = 12;
rca_size = 4;
xlr_radius = 12;
xlr_diam = xlr_radius;
m3_holesize = 3.4/2;


difference() {
  cube( [ width, depth, height ] );
    // Subwoofer
    translate( [ subwoofer_input_x, 1, y2 ] ) { 
        rotate( [ 90, 0, 0] ) {
            cylinder( 2, rca_size, rca_size );
        }
    }   
   
   // IR receiver remote
   translate( [ subwoofer_input_x, 1, y1 ] ) { 
        rotate( [ 90, 0, 0] ) {
            cylinder( 2, 3.1, 3.1 );
        }
    }    
    
    // XLR jack
     translate( [ xlr_input_x, 1, y2 ] ) { 
        rotate( [ 90, 0, 0] ) {
            cylinder( 2, xlr_size, xlr_size );
        }
    }
    
     translate( [ xlr_input_x + 50, 1, y2  ] ) { 
        rotate( [ 90, 0, 0] ) {
            cylinder( 2, xlr_size, xlr_size );
        }
    }
    
     // Audio L/R out jack
    translate( [ xlr_input_x + rca_dist/1.5, 1, y1 ] ) { 
        rotate( [ 90, 0, 0] ) {
            cylinder( 2, rca_size, rca_size );
        }
    }
    
    translate( [ xlr_input_x - rca_dist/1.5, 1, y1 ] ) { 
        rotate( [ 90, 0, 0] ) {
            cylinder( 2, rca_size, rca_size );
        }
    }
    
    translate( [ xlr_input_x + 50 + rca_dist/1.5, 1, y1  ] ) { 
        rotate( [ 90, 0, 0] ) {
            cylinder( 2, rca_size, rca_size );
        }
    }
    
    translate( [ xlr_input_x + 50 - rca_dist/1.5, 1, y1  ] ) { 
        rotate( [ 90, 0, 0] ) {
            cylinder( 2, rca_size, rca_size );
        }
    }
   
   
    // SPDIF inputs
    translate( [ spdif_input_x, 0, y1 ] ) { 
        rotate( [ 90, 0, 0] ) {
            cylinder( 2, rca_size, rca_size );
        }
    }
    
    translate( [ spdif_input_x, 0, y2 ] ) { 
        rotate( [ 90, 0, 0] ) {
            cylinder( 2, rca_size, rca_size );
        }
    }
    
    translate( [ spdif_input_x + rca_dist, 1, y1 ] ) { 
        rotate( [ 90, 0, 0 ] ) {
            cylinder( 2, rca_size, rca_size );
        }
    }
    
    translate( [ spdif_input_x + rca_dist, 1, y2 ] ) { 
        rotate( [ 90, 0, 0] ) {
            cylinder( 2, rca_size, rca_size );
        }
    } 
    
    
    // RCA inputs
    translate( [ rca_input_x, 0, y1 ] ) { 
        rotate( [ 90, 0, 0] ) {
            cylinder( 2, rca_size, rca_size );
        }
    }
    
    translate( [ rca_input_x, 0, y2 ] ) { 
        rotate( [ 90, 0, 0] ) {
            cylinder( 2, rca_size, rca_size );
        }
    }
    
    translate( [ rca_input_x + rca_dist, 1, y1 ] ) { 
        rotate( [ 90, 0, 0 ] ) {
            cylinder( 2, rca_size, rca_size );
        }
    }
    
    translate( [ rca_input_x + rca_dist, 1, y2 ] ) { 
        rotate( [ 90, 0, 0] ) {
            cylinder( 2, rca_size, rca_size );
        }
    } 
 
     translate( [ rca_input_x + rca_dist*2, 1, y1 ] ) { 
        rotate( [ 90, 0, 0] ) {
            cylinder( 2, rca_size, rca_size );
        }
    }
    
    translate( [ rca_input_x + rca_dist*2, 1, y2 ] ) { 
        rotate( [ 90, 0, 0] ) {
            cylinder( 2, rca_size, rca_size );
        }
    }  
     translate( [ rca_input_x + rca_dist*3, 1, y1 ] ) { 
        rotate( [ 90, 0, 0] ) {
            cylinder( 2, rca_size, rca_size );
        }
    }
    
    translate( [ rca_input_x + rca_dist*3, 1, y2 ] ) { 
        rotate( [ 90, 0, 0] ) {
            cylinder( 2, rca_size, rca_size );
        }
    } 
    
     translate( [ rca_input_x + rca_dist*4, 1, y1 ] ) { 
        rotate( [ 90, 0, 0] ) {
            cylinder( 2, rca_size, rca_size );
        }
    }
    
    translate( [ rca_input_x + rca_dist*4, 1, y2 ] ) { 
        rotate( [ 90, 0, 0] ) {
            cylinder( 2, rca_size, rca_size );
        }
    } 
    
    // usb
    translate( [ usb_input_x, 1, y2 ] ) { 
        rotate( [ 90, 0, 0] ) {
            cylinder( 2, usb_size, usb_size );
        }
    } 
    
    // reset
    translate( [ usb_input_x, 1, y1 ] ) { 
        rotate( [ 90, 0, 0] ) {
            cylinder( 2, reset_size, reset_size );
        }
    } 
}

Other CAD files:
PCBs/AURORA/_Render/amp3.scad
PCBs/AURORA/_Render/bezel.scad

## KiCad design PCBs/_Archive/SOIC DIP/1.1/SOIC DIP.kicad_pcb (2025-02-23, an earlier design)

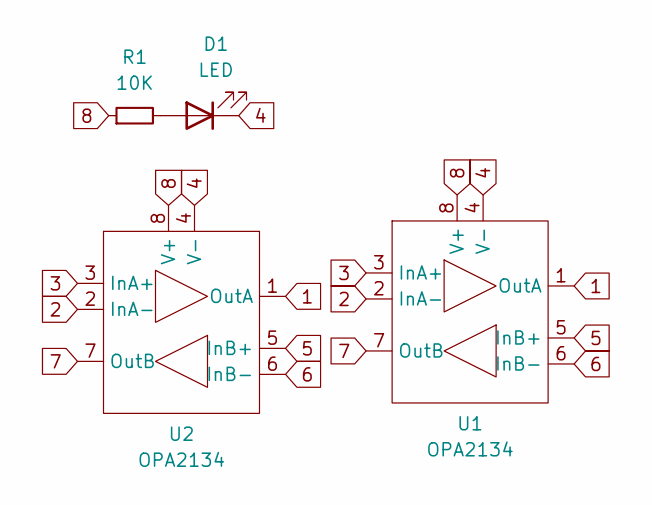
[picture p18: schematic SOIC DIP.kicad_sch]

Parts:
D1: LED; R_0603_1608Metric
R1: 10K; R_0603_1608Metric
U1: OPA2134; DIP-8_W7.62mm_Socket
U2: OPA2134; SOIC-8_3.9x4.9mm_P1.27mm

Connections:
1: U1.1 (OutA), U2.1 (OutA)
2: U1.2 (InA-), U2.2 (InA-)
3: U1.3 (InA+), U2.3 (InA+)
4: D1.1 (K), U1.4 (V-), U2.4 (V-)
5: U1.5 (InB+), U2.5 (InB+)
6: U1.6 (InB-), U2.6 (InB-)
7: U1.7 (OutB), U2.7 (OutB)
8: R1.1, U1.8 (V+), U2.8 (V+)
unnamed: D1.2 (A), R1.2

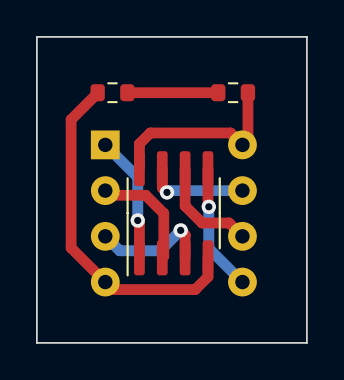
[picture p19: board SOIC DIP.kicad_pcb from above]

Board: 2 copper layers, 15.0 x 17.0 mm, 4 parts (0 on the bottom side), 9 nets.

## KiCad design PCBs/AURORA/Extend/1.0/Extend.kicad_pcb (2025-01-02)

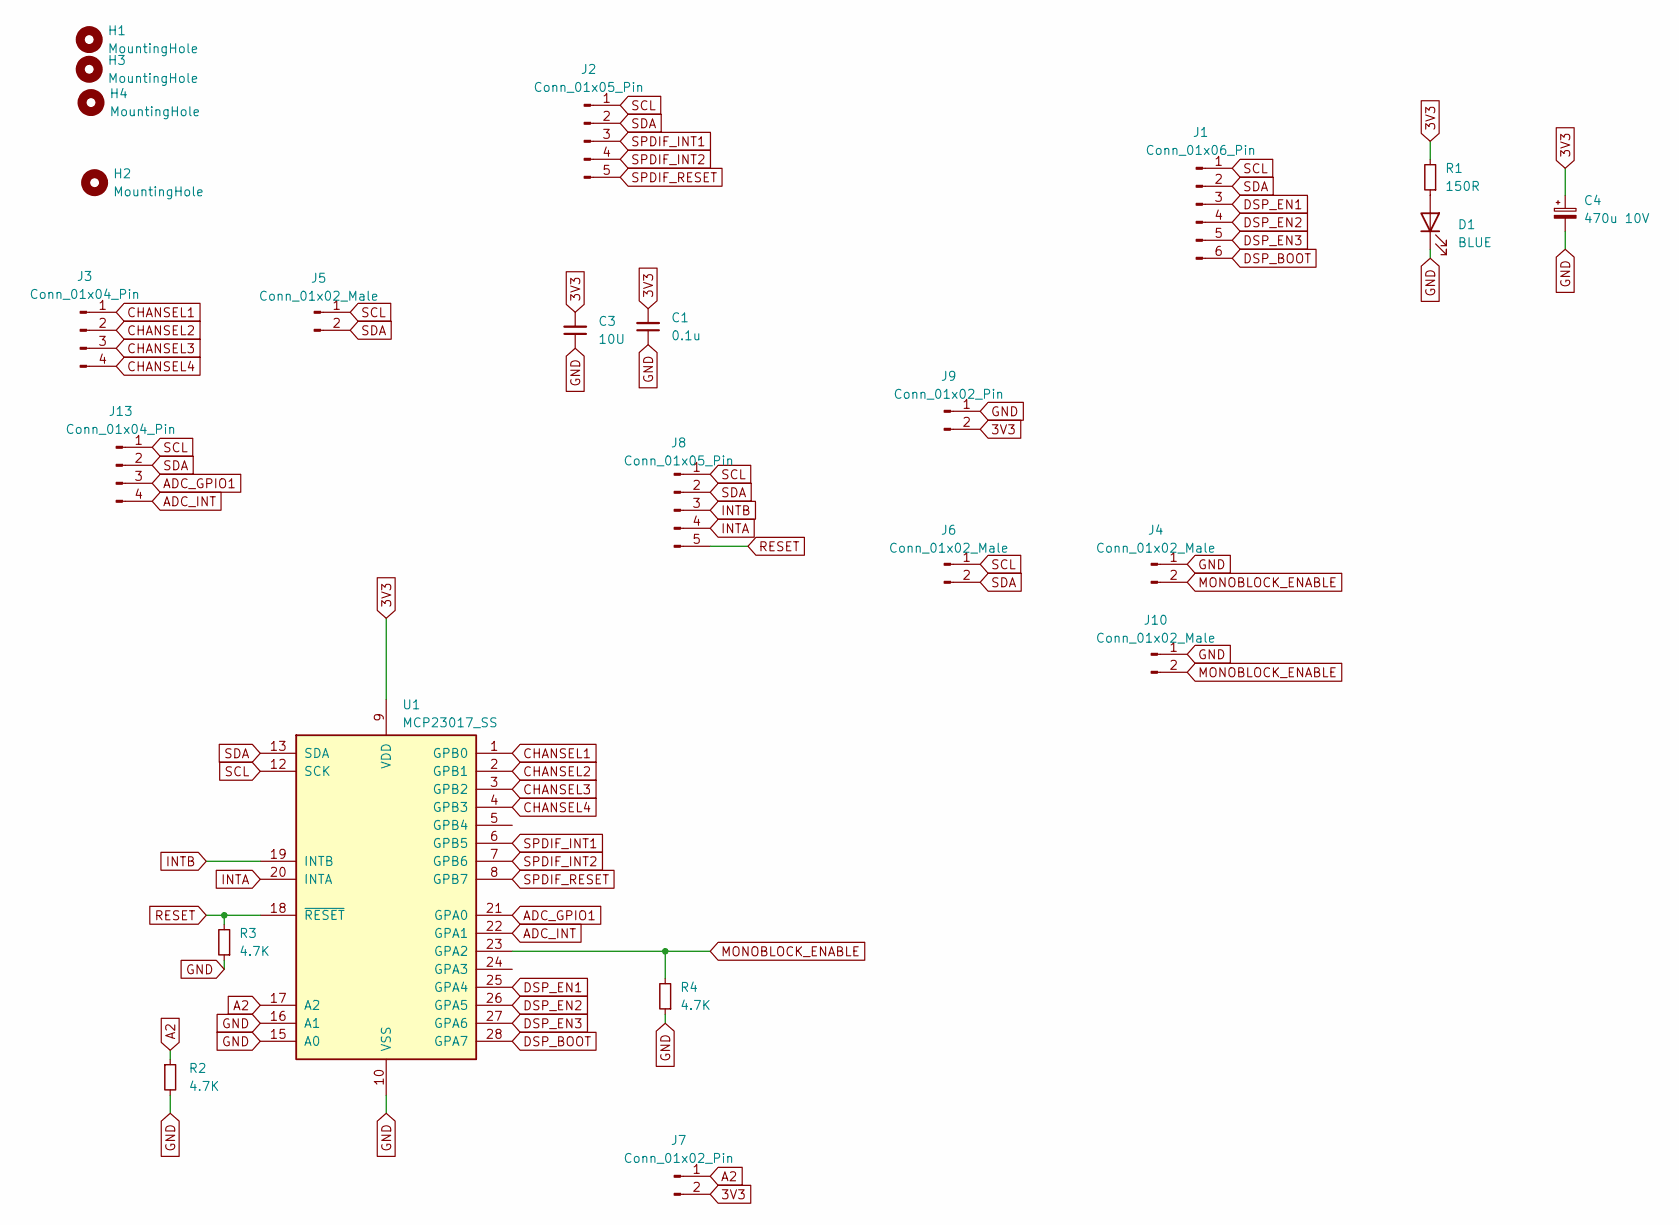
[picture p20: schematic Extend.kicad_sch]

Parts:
C1: 0.1u; C_0805_2012Metric_Pad1.18x1.45mm_HandSolder
C3: 10U; C_1206_3216Metric_Pad1.33x1.80mm_HandSolder
C4: 470u 10V; CP_Radial_D6.3mm_P2.50mm
D1: BLUE; LED_0603_1608Metric
H1, H2, H3, H4: MountingHole; MountingHole_3.2mm_M3_DIN965_Pad_TopOnly
J1: Conn_01x06_Pin; JST_PH_B6B-PH-K_1x06_P2.00mm_Vertical
J2, J8: Conn_01x05_Pin; JST_PH_B5B-PH-K_1x05_P2.00mm_Vertical
J3, J13: Conn_01x04_Pin; JST_PH_B4B-PH-K_1x04_P2.00mm_Vertical
J4, J5, J6, J10: Conn_01x02_Male; JST_PH_B2B-PH-K_1x02_P2.00mm_Vertical
J7: Conn_01x02_Pin; PinHeader_1x02_P2.54mm_Vertical
J9: Conn_01x02_Pin; JST_PH_B2B-PH-K_1x02_P2.00mm_Vertical
R1: 150R; R_0603_1608Metric
R2, R3, R4: 4.7K; R_0603_1608Metric_Pad0.98x0.95mm_HandSolder
U1: MCP23017_SS; SSOP-28_5.3x10.2mm_P0.65mm

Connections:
3V3: C1.2, C3.2, C4.1, J7.2, J9.2, R1.2, U1.9 (VDD)
A2: J7.1, R2.1, U1.17 (A2)
ADC_GPIO1: J13.3, U1.21 (GPA0)
ADC_INT: J13.4, U1.22 (GPA1)
CHANSEL1: J3.1, U1.1 (GPB0)
CHANSEL2: J3.2, U1.2 (GPB1)
CHANSEL3: J3.3, U1.3 (GPB2)
CHANSEL4: J3.4, U1.4 (GPB3)
DSP_BOOT: J1.6, U1.28 (GPA7)
DSP_EN1: J1.3, U1.25 (GPA4)
DSP_EN2: J1.4, U1.26 (GPA5)
DSP_EN3: J1.5, U1.27 (GPA6)
GND: C1.1, C3.1, C4.2, D1.1 (K), J4.1, J9.1, J10.1, R2.2, R3.1, R4.1, U1.10 (VSS), U1.15 (A0), U1.16 (A1)
INTA: J8.4, U1.20 (INTA)
INTB: J8.3, U1.19 (INTB)
MONOBLOCK_ENABLE: J4.2, J10.2, R4.2, U1.23 (GPA2)
unnamed: D1.2 (A), R1.1
RESET: J8.5, R3.2, U1.18 (~RESET)
SCL: J1.1, J2.1, J5.1, J6.1, J8.1, J13.1, U1.12 (SCK)
SDA: J1.2, J2.2, J5.2, J6.2, J8.2, J13.2, U1.13 (SDA)
SPDIF_INT1: J2.3, U1.6 (GPB5)
SPDIF_INT2: J2.4, U1.7 (GPB6)
SPDIF_RESET: J2.5, U1.8 (GPB7)

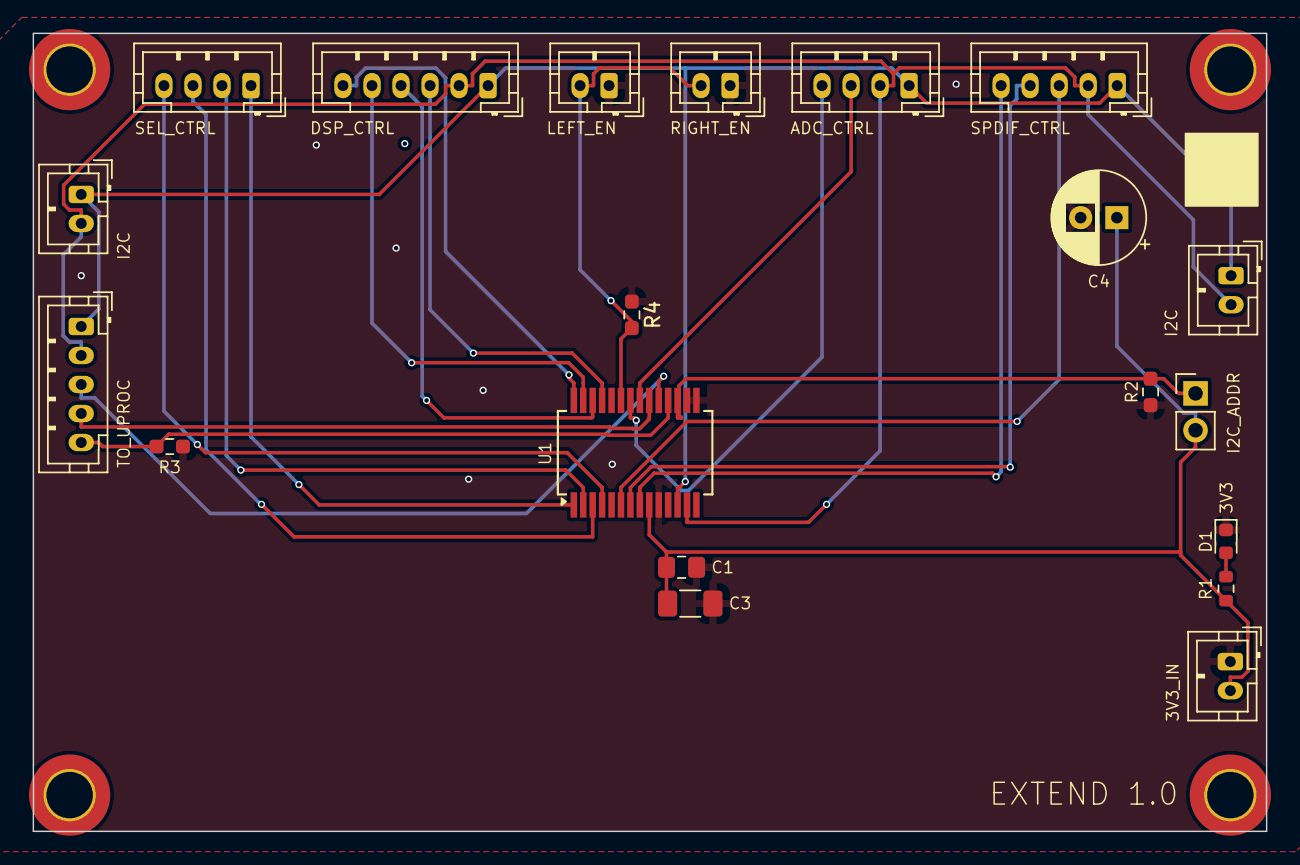
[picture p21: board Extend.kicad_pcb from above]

Board: 2 copper layers, 85.0 x 55.0 mm, 24 parts (0 on the bottom side), 23 nets.

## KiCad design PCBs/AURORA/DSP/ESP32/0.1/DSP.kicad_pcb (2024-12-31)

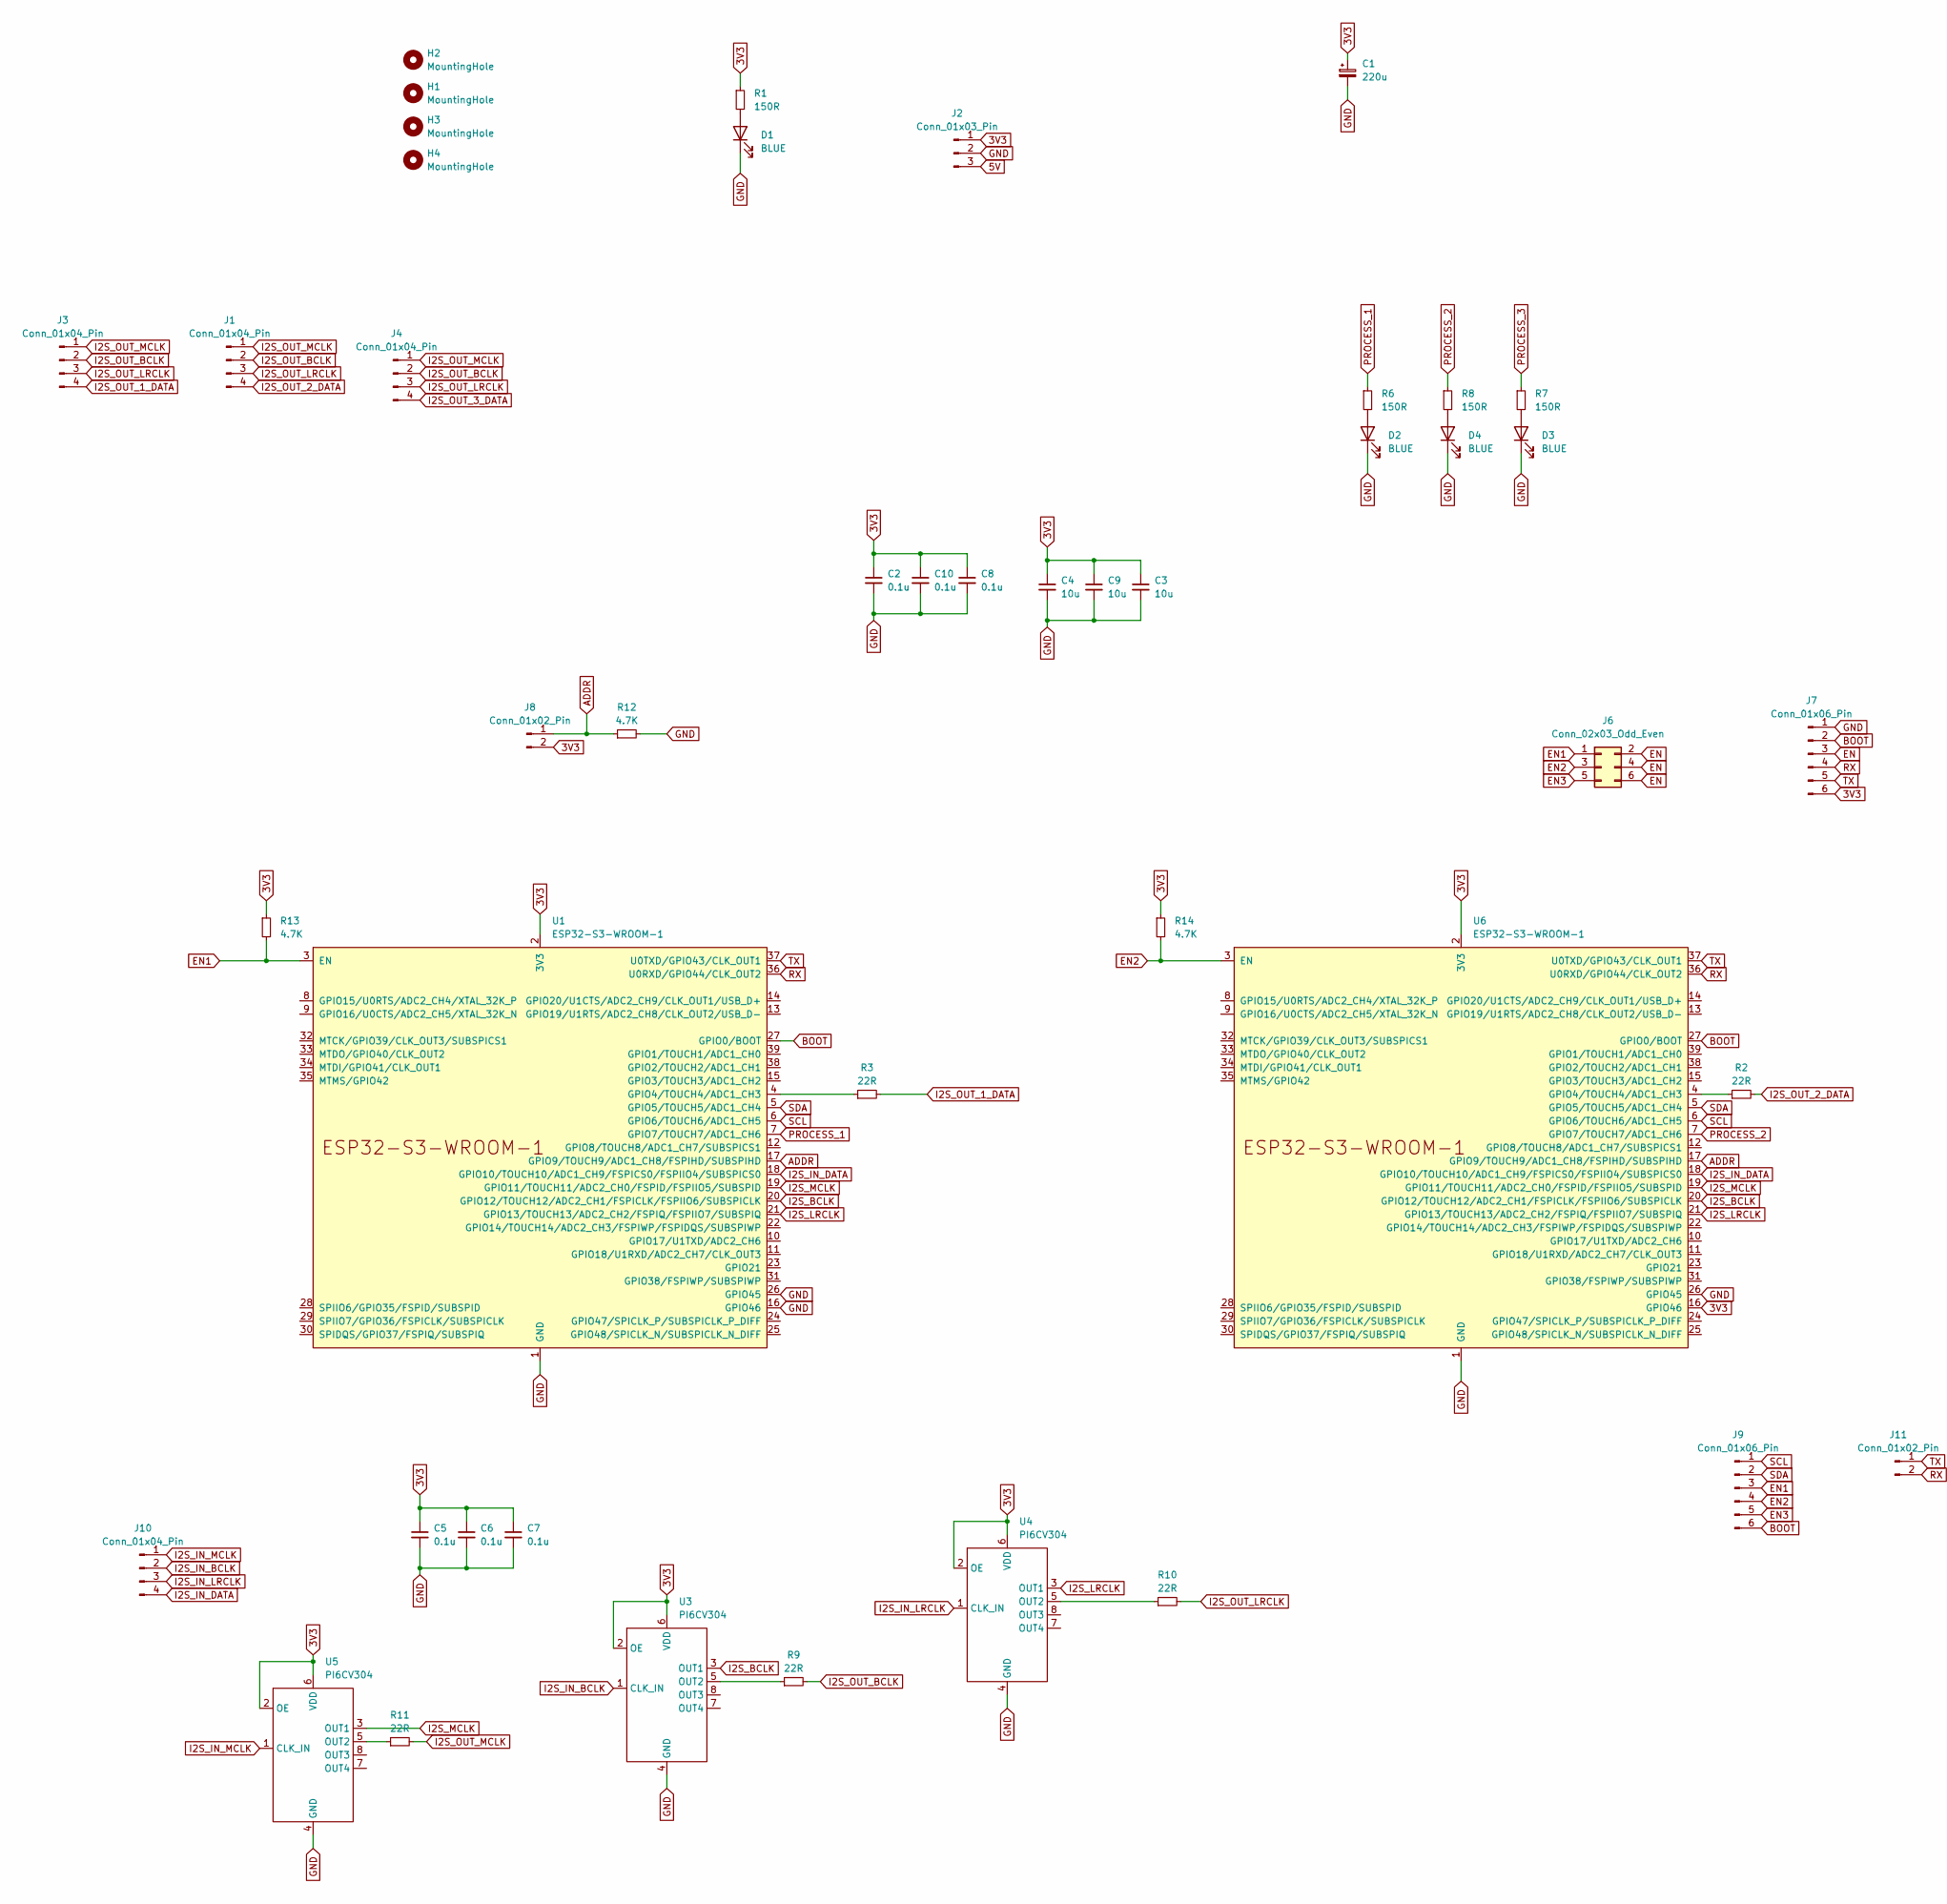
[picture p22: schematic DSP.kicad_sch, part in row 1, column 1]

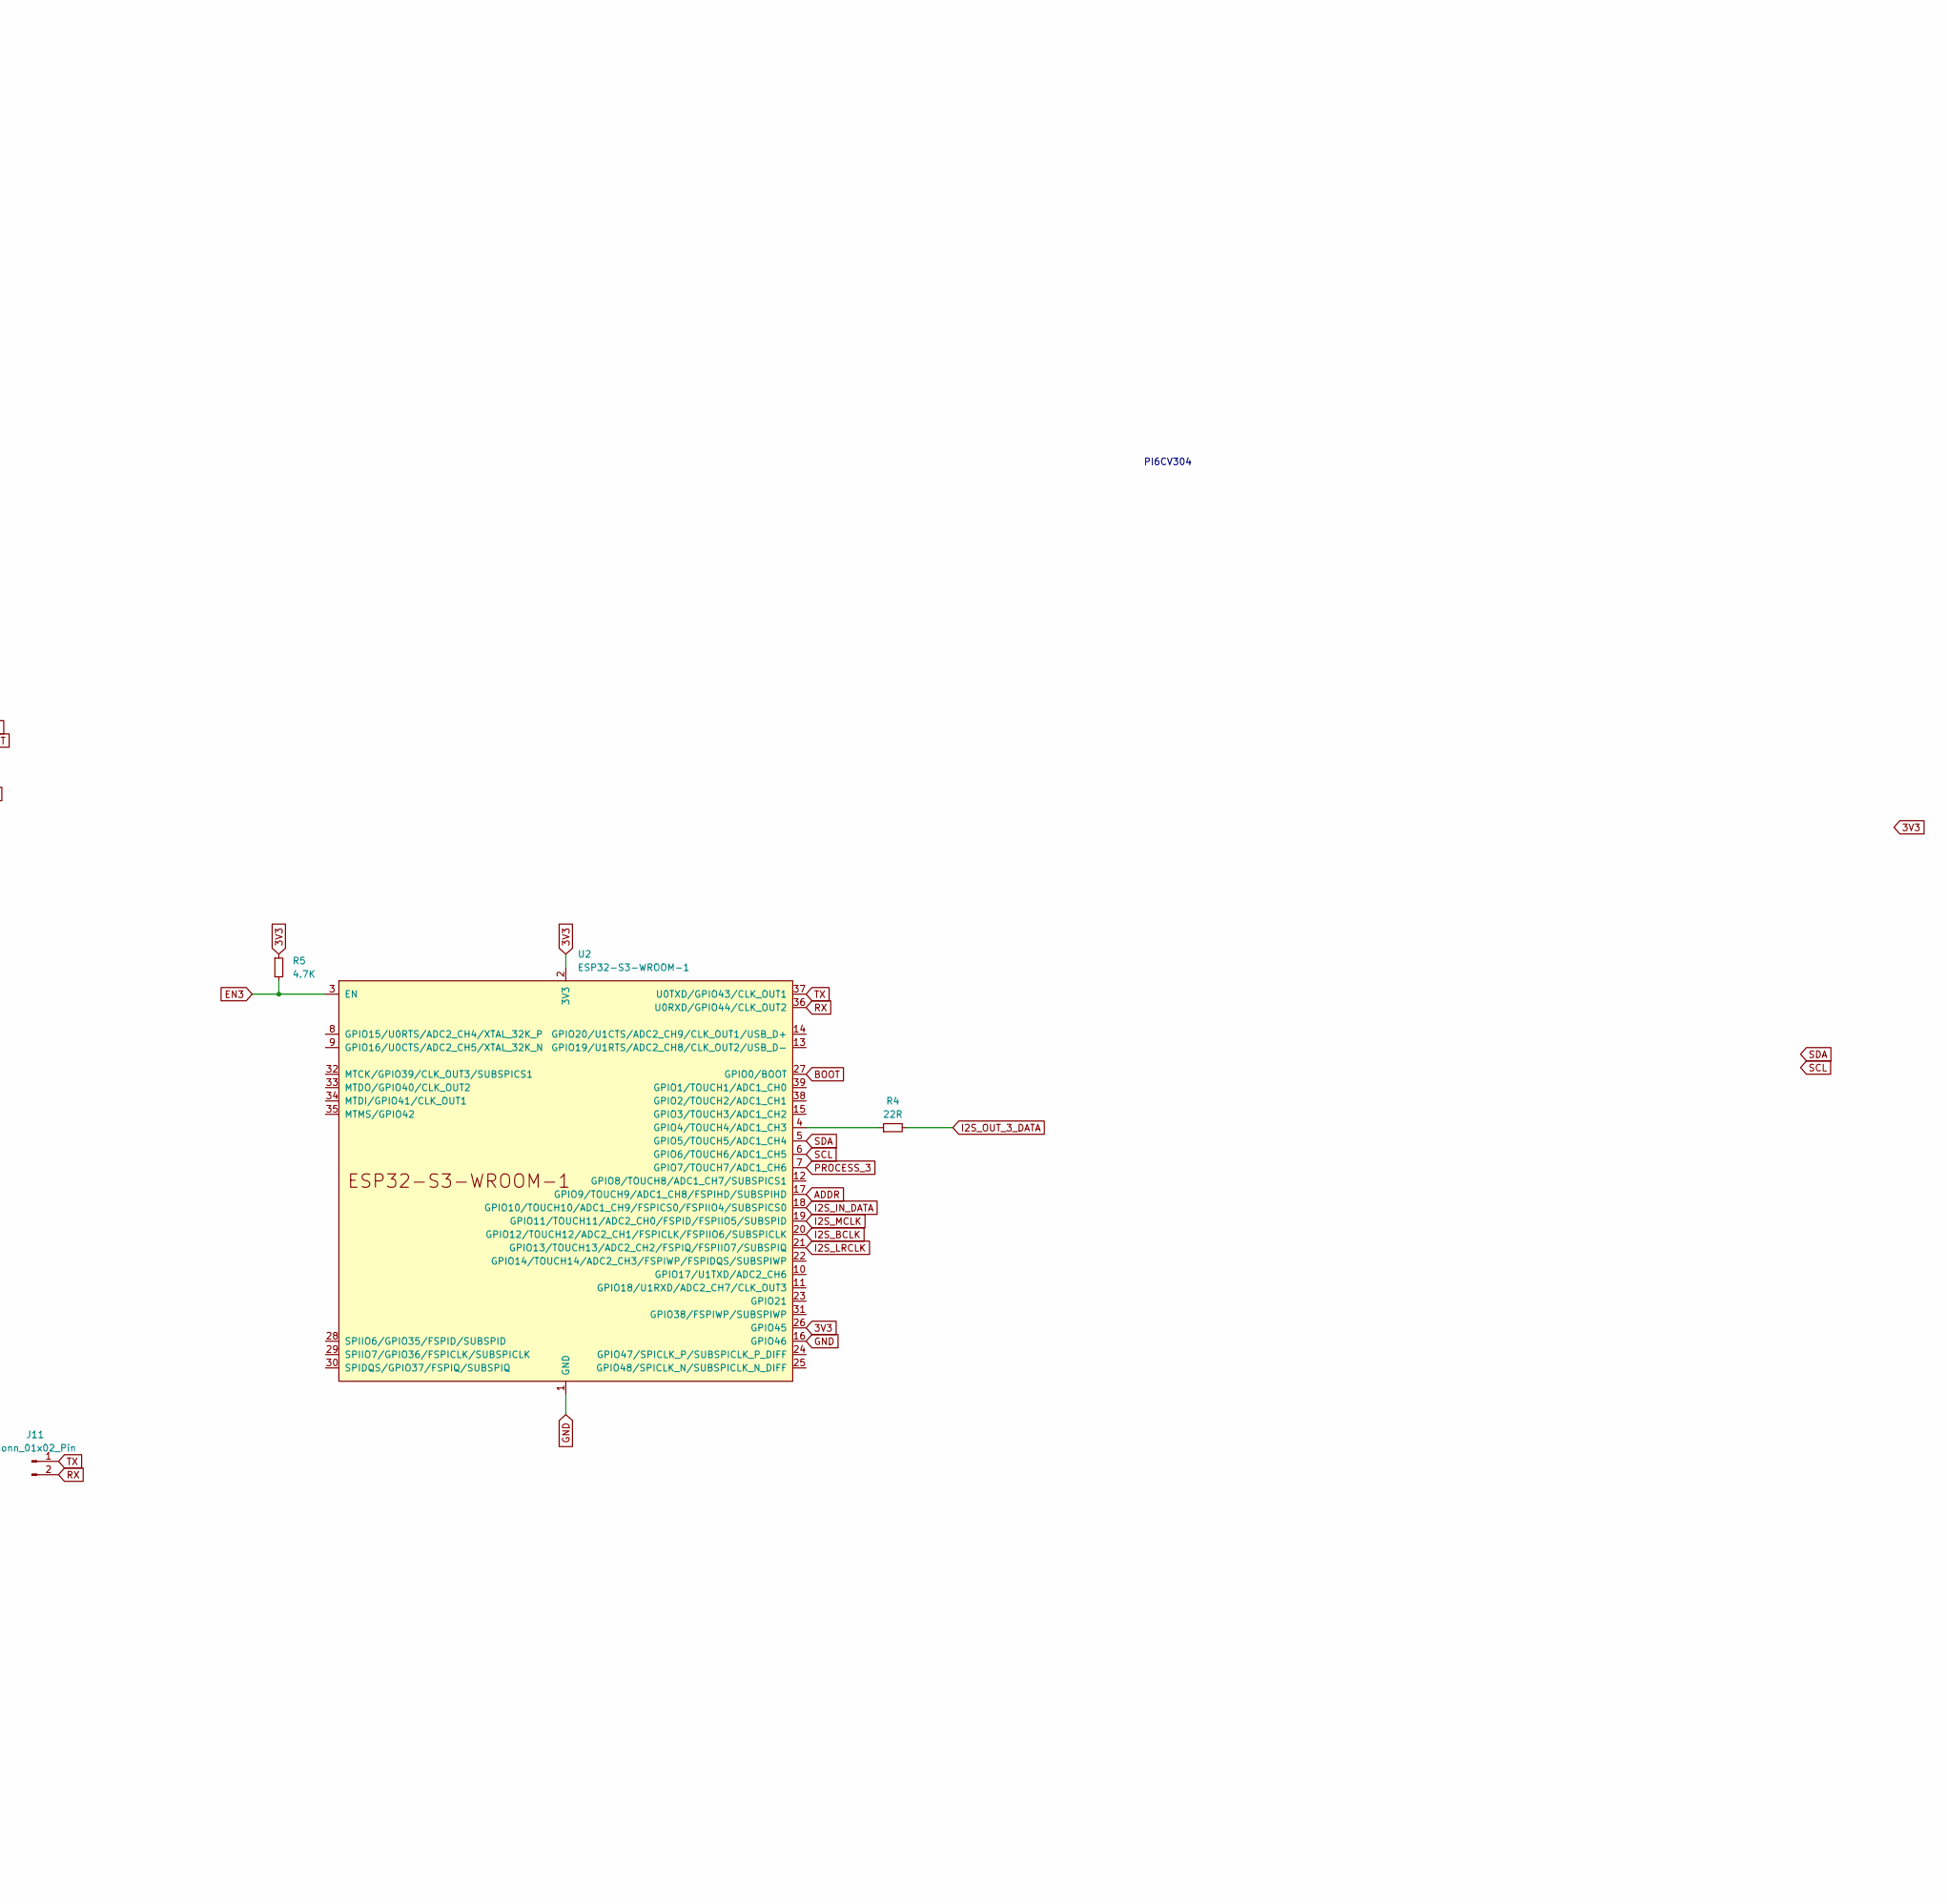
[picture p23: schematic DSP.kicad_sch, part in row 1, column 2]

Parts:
C1: 220u; CP_Radial_D6.3mm_P2.50mm; LCSC C4747974
C2, C5, C6, C7, C8, C10: 0.1u; C_0603_1608Metric_Pad1.08x0.95mm_HandSolder
C3, C4, C9: 10u; C_0805_2012Metric_Pad1.18x1.45mm_HandSolder
D1, D2, D3, D4: BLUE; D_0603_1608Metric; LCSC C84259
H1, H2, H3, H4: MountingHole; MountingHole_3.2mm_M3_DIN965_Pad_TopOnly
J1, J3, J4, J10: Conn_01x04_Pin; JST_PH_B4B-PH-K_1x04_P2.00mm_Vertical
J2: Conn_01x03_Pin; JST_PH_B3B-PH-K_1x03_P2.00mm_Vertical
J6: Conn_02x03_Odd_Even; PinHeader_2x03_P2.54mm_Vertical
J7: Conn_01x06_Pin; PinHeader_1x06_P2.54mm_Vertical
J8: Conn_01x02_Pin; PinHeader_1x02_P2.54mm_Vertical
J9: Conn_01x06_Pin; JST_PH_B6B-PH-K_1x06_P2.00mm_Vertical
J11: Conn_01x02_Pin; JST_PH_B2B-PH-K_1x02_P2.00mm_Vertical
R1, R6, R7, R8: 150R; R_0603_1608Metric; LCSC C22808
R2, R3, R4, R9, R10, R11: 22R; R_0603_1608Metric
R5, R12, R13, R14: 4.7K; R_0603_1608Metric; LCSC C23162
U1, U2, U6: ESP32-S3-WROOM-1; Mouser 356-ESP32S3WRM1N16R8
U3, U4, U5: PI6CV304; TSSOP-8_4.4x3mm_P0.65mm

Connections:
3V3: C1.1, C2.1, C3.1, C4.1, C5.1, C6.1, C7.1, C8.1, C9.1, C10.1, J2.1, J7.6, J8.2, R1.1, R5.1, R13.1, R14.1, U1.2 (3V3), U2.2 (3V3), U2.26 (GPIO45), U3.2 (OE), U3.6 (VDD), U4.2 (OE), U4.6 (VDD), U5.2 (OE), U5.6 (VDD), U6.2 (3V3), U6.16 (GPIO46)
5V: J2.3
ADDR: J8.1, R12.1, U1.17 (GPIO9/TOUCH9/ADC1_CH8/FSPIHD/SUBSPIHD), U2.17 (GPIO9/TOUCH9/ADC1_CH8/FSPIHD/SUBSPIHD), U6.17 (GPIO9/TOUCH9/ADC1_CH8/FSPIHD/SUBSPIHD)
BOOT: J7.2, J9.6, U1.27 (GPIO0/BOOT), U2.27 (GPIO0/BOOT), U6.27 (GPIO0/BOOT)
EN: J6.2, J6.4, J6.6, J7.3
EN1: J6.1, J9.3, R13.2, U1.3 (EN)
EN2: J6.3, J9.4, R14.2, U6.3 (EN)
EN3: J6.5, J9.5, R5.2, U2.3 (EN)
GND: C1.2, C2.2, C3.2, C4.2, C5.2, C6.2, C7.2, C8.2, C9.2, C10.2, D1.1 (K), D2.1 (K), D3.1 (K), D4.1 (K), J2.2, J7.1, R12.2, U1.1 (GND), U1.16 (GPIO46), U1.26 (GPIO45), U1.40 (GND), U1.41 (GND), U2.1 (GND), U2.16 (GPIO46), U2.40 (GND), U2.41 (GND), U3.4 (GND), U4.4 (GND), U5.4 (GND), U6.1 (GND), U6.26 (GPIO45), U6.40 (GND), U6.41 (GND)
I2S_BCLK: U1.20 (GPIO12/TOUCH12/ADC2_CH1/FSPICLK/FSPIIO6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), U2.20 (GPIO12/TOUCH12/ADC2_CH1/FSPICLK/FSPIIO6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), U3.3 (OUT1), U6.20 (GPIO12/TOUCH12/ADC2_CH1/FSPICLK/FSPIIO6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)
I2S_IN_BCLK: J10.2, U3.1 (CLK_IN)
I2S_IN_DATA: J10.4, U1.18 (GPIO10/TOUCH10/ADC1_CH9/FSPICS0/FSPIIO4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), U2.18 (GPIO10/TOUCH10/ADC1_CH9/FSPICS0/FSPIIO4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), U6.18 (GPIO10/TOUCH10/ADC1_CH9/FSPICS0/FSPIIO4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)
I2S_IN_LRCLK: J10.3, U4.1 (CLK_IN)
I2S_IN_MCLK: J10.1, U5.1 (CLK_IN)
I2S_LRCLK: U1.21 (GPIO13/TOUCH13/ADC2_CH2/FSPIQ/FSPIIO7/S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), U2.21 (GPIO13/TOUCH13/ADC2_CH2/FSPIQ/FSPIIO7/S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), U4.3 (OUT1), U6.21 (GPIO13/TOUCH13/ADC2_CH2/FSPIQ/FSPIIO7/S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)
I2S_MCLK: U1.19 (GPIO11/TOUCH11/ADC2_CH0/FSPID/FSPIIO5/S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), U2.19 (GPIO11/TOUCH11/ADC2_CH0/FSPID/FSPIIO5/S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), U5.3 (OUT1), U6.19 (GPIO11/TOUCH11/ADC2_CH0/FSPID/FSPIIO5/S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)
I2S_OUT_1_DATA: J3.4, R3.2
I2S_OUT_2_DATA: J1.4, R2.2
I2S_OUT_3_DATA: J4.4, R4.2
I2S_OUT_BCLK: J1.2, J3.2, J4.2, R9.2
I2S_OUT_LRCLK: J1.3, J3.3, J4.3, R10.2
I2S_OUT_MCLK: J1.1, J3.1, J4.1, R11.2
unnamed: D1.2 (A), R1.2
unnamed: D2.2 (A), R6.2
unnamed: D3.2 (A), R7.2
unnamed: D4.2 (A), R8.2
unnamed: R3.1, U1.4 (GPIO4/TOUCH4/ADC1_CH3)
unnamed: R4.1, U2.4 (GPIO4/TOUCH4/ADC1_CH3)
unnamed: R9.1, U3.5 (OUT2)
unnamed: R10.1, U4.5 (OUT2)
unnamed: R11.1, U5.5 (OUT2)
unnamed: R2.1, U6.4 (GPIO4/TOUCH4/ADC1_CH3)
PROCESS_1: R6.1, U1.7 (GPIO7/TOUCH7/ADC1_CH6)
PROCESS_2: R8.1, U6.7 (GPIO7/TOUCH7/ADC1_CH6)
PROCESS_3: R7.1, U2.7 (GPIO7/TOUCH7/ADC1_CH6)
RX: J7.4, J11.2, U1.36 (U0RXD/GPIO44/CLK_OUT2), U2.36 (U0RXD/GPIO44/CLK_OUT2), U6.36 (U0RXD/GPIO44/CLK_OUT2)
SCL: J9.1, U1.6 (GPIO6/TOUCH6/ADC1_CH5), U2.6 (GPIO6/TOUCH6/ADC1_CH5), U6.6 (GPIO6/TOUCH6/ADC1_CH5)
SDA: J9.2, U1.5 (GPIO5/TOUCH5/ADC1_CH4), U2.5 (GPIO5/TOUCH5/ADC1_CH4), U6.5 (GPIO5/TOUCH5/ADC1_CH4)
TX: J7.5, J11.1, U1.37 (U0TXD/GPIO43/CLK_OUT1), U2.37 (U0TXD/GPIO43/CLK_OUT1), U6.37 (U0TXD/GPIO43/CLK_OUT1)

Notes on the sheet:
PI6CV304

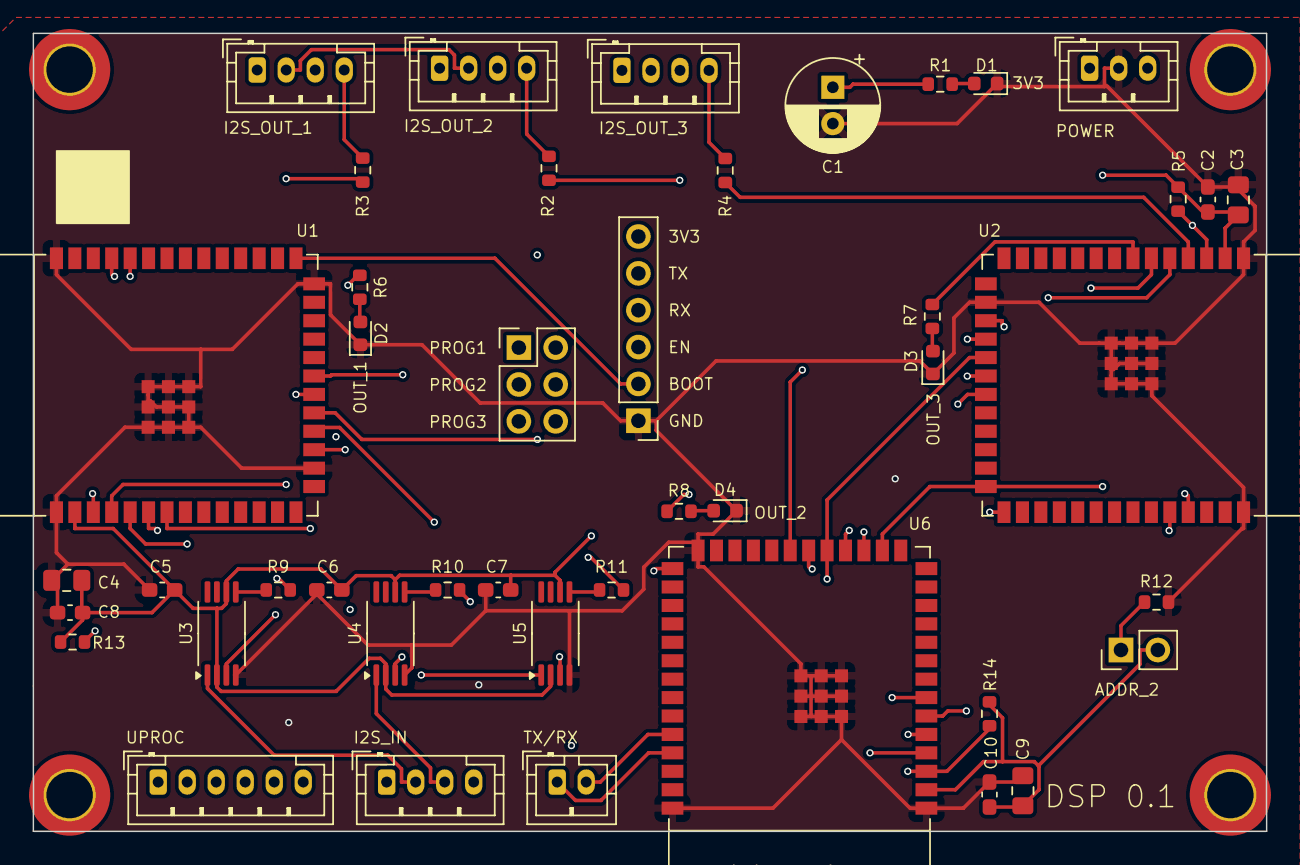
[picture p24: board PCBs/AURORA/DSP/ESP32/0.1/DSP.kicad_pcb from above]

Board: 4 copper layers, 85.0 x 55.0 mm, 48 parts (0 on the bottom side), 38 nets.

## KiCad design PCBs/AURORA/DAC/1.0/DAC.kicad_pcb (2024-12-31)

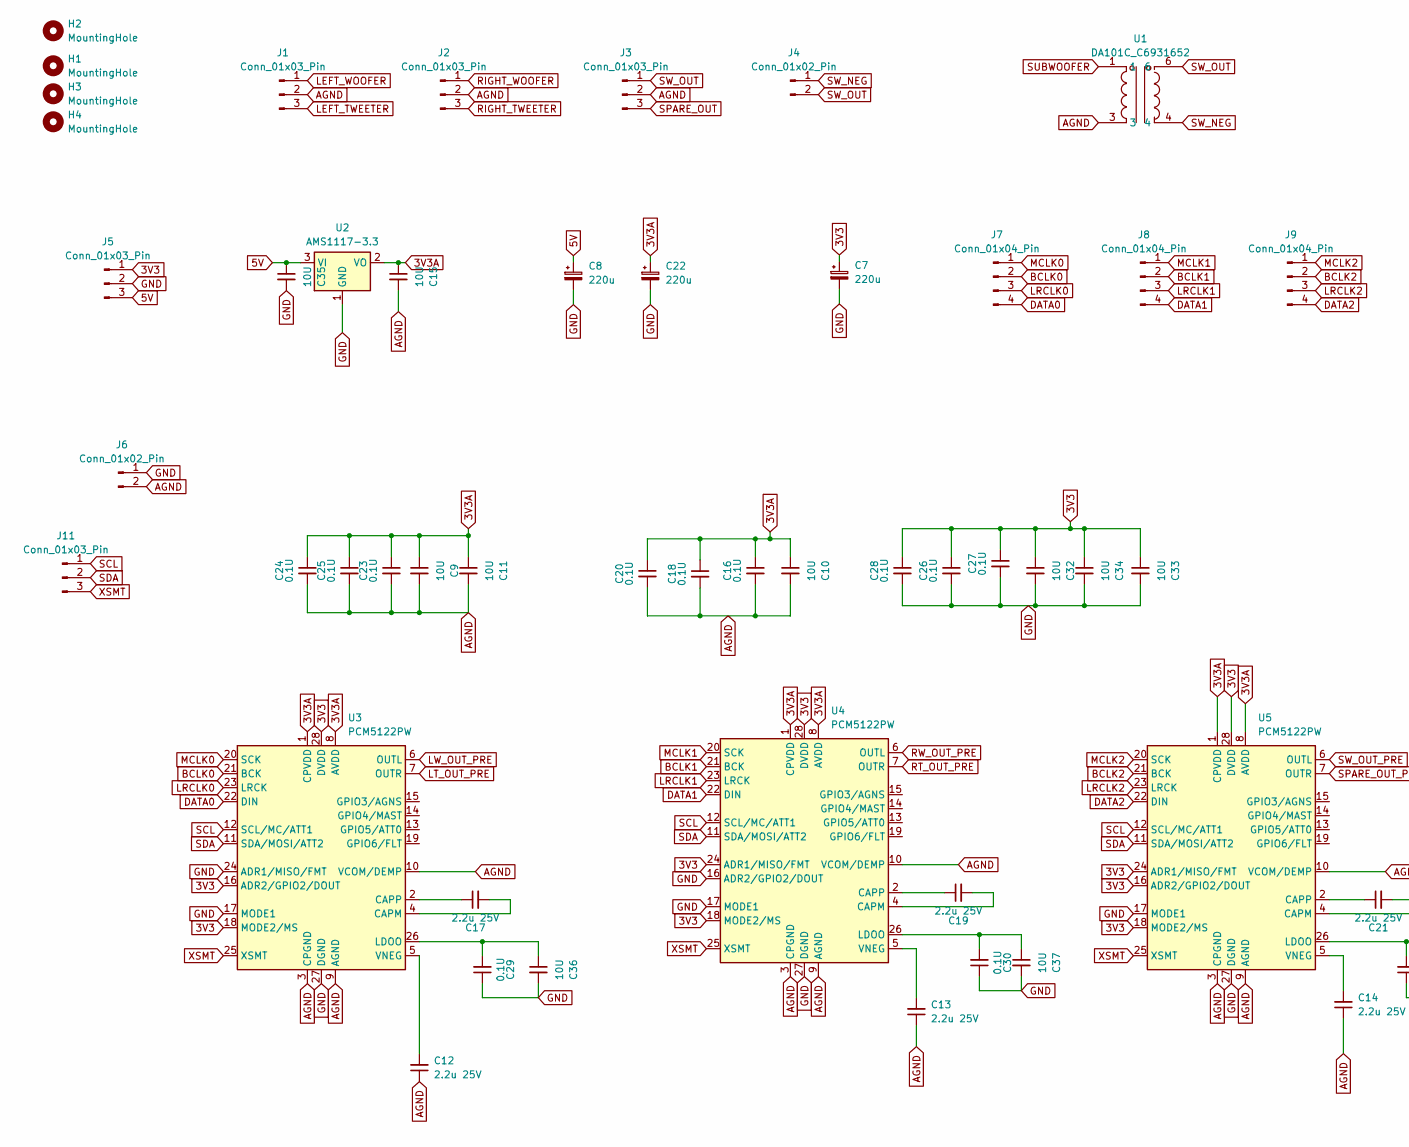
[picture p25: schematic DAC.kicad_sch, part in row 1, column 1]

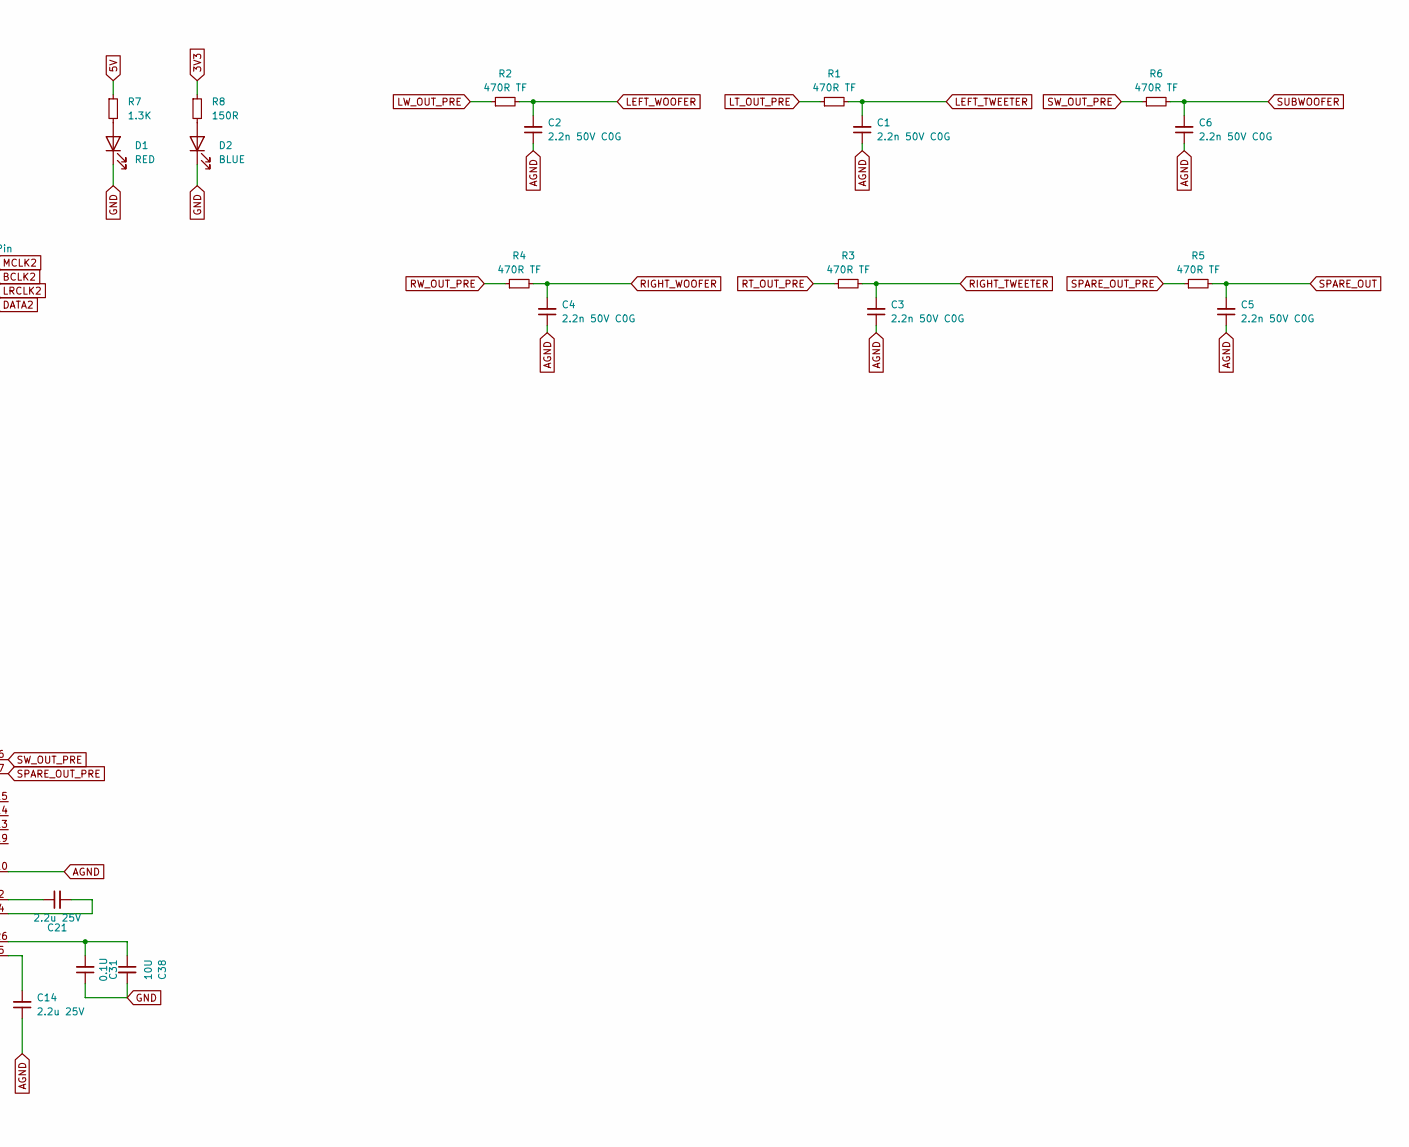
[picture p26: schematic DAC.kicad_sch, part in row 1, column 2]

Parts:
C1, C2, C3, C4: 2.2n 50V C0G; C_0805_2012Metric_Pad1.18x1.45mm_HandSolder; Mouser 791-0805N222F500CT
C5, C6: 2.2n 50V C0G; C_0805_2012Metric_Pad1.18x1.45mm_HandSolder
C7, C8, C22: 220u; CP_Radial_D6.3mm_P2.50mm
C9, C10, C11, C15, C32, C33, C34, C35, C36, C37, C38: 10U; C_1206_3216Metric_Pad1.33x1.80mm_HandSolder
C12, C13, C14: 2.2u 25V; C_1206_3216Metric_Pad1.33x1.80mm_HandSolder
C16, C18, C20, C23, C24, C25, C26, C27, C28, C29, C30, C31: 0.1U; C_0805_2012Metric_Pad1.18x1.45mm_HandSolder
C17, C19, C21: 2.2u 25V; C_0805_2012Metric_Pad1.18x1.45mm_HandSolder
D1: RED; LED_0603_1608Metric
D2: BLUE; LED_0603_1608Metric
H1, H2, H3, H4: MountingHole; MountingHole_3.2mm_M3_DIN965_Pad_TopOnly
J1, J2, J3, J5, J11: Conn_01x03_Pin; JST_PH_B3B-PH-K_1x03_P2.00mm_Vertical
J4: Conn_01x02_Pin; JST_PH_B2B-PH-K_1x02_P2.00mm_Vertical
J6: Conn_01x02_Pin; PinHeader_1x02_P2.54mm_Vertical
J7, J8, J9: Conn_01x04_Pin; JST_PH_B4B-PH-K_1x04_P2.00mm_Vertical
R1, R2, R3, R4, R5, R6: 470R TF; R_0805_2012Metric_Pad1.20x1.40mm_HandSolder; Mouser 603-RT0805FRE07470RL
R7: 1.3K; R_0603_1608Metric_Pad0.98x0.95mm_HandSolder
R8: 150R; R_0603_1608Metric_Pad0.98x0.95mm_HandSolder
U1: DA101C_C6931652; XFMR-TH_4P-L9.5-W9.0-P5.08-LS10.2_C9900096976; LCSC Part C6931652
U2: AMS1117-3.3; SOT-223-3_TabPin2
U3, U4, U5: PCM5122PW; TSSOP-28_4.4x9.7mm_P0.65mm; Mouser 595-PCM5142PWR

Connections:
3V3: C7.1, C26.1, C27.1, C28.1, C32.1, C33.1, C34.1, J5.1, R8.1, U3.16 (ADR2/GPIO2/DOUT), U3.18 (MODE2/MS), U3.28 (DVDD), U4.18 (MODE2/MS), U4.24 (ADR1/MISO/FMT), U4.28 (DVDD), U5.16 (ADR2/GPIO2/DOUT), U5.18 (MODE2/MS), U5.24 (ADR1/MISO/FMT), U5.28 (DVDD)
3V3A: C9.1, C10.1, C11.1, C15.1, C16.1, C18.1, C20.1, C22.1, C23.1, C24.1, C25.1, U2.2 (VO), U3.1 (CPVDD), U3.8 (AVDD), U4.1 (CPVDD), U4.8 (AVDD), U5.1 (CPVDD), U5.8 (AVDD)
5V: C8.1, C35.1, J5.3, R7.1, U2.3 (VI)
AGND: C1.1, C2.1, C3.1, C4.1, C5.1, C6.1, C9.2, C10.2, C11.2, C12.1, C13.1, C14.1, C15.2, C16.2, C18.2, C20.2, C23.2, C24.2, C25.2, J1.2, J2.2, J3.2, J6.2, U1.3, U3.3 (CPGND), U3.9 (AGND), U3.10 (VCOM/DEMP), U4.3 (CPGND), U4.9 (AGND), U4.10 (VCOM/DEMP), U5.3 (CPGND), U5.9 (AGND), U5.10 (VCOM/DEMP)
BCLK0: J7.2, U3.21 (BCK)
BCLK1: J8.2, U4.21 (BCK)
BCLK2: J9.2, U5.21 (BCK)
DATA0: J7.4, U3.22 (DIN)
DATA1: J8.4, U4.22 (DIN)
DATA2: J9.4, U5.22 (DIN)
GND: C7.2, C8.2, C22.2, C26.2, C27.2, C28.2, C29.1, C30.1, C31.1, C32.2, C33.2, C34.2, C35.2, C36.2, C37.2, C38.2, D1.1 (K), D2.1 (K), J5.2, J6.1, U2.1 (GND), U3.17 (MODE1), U3.24 (ADR1/MISO/FMT), U3.27 (DGND), U4.16 (ADR2/GPIO2/DOUT), U4.17 (MODE1), U4.27 (DGND), U5.17 (MODE1), U5.27 (DGND)
LEFT_TWEETER: C1.2, J1.3, R1.2
LEFT_WOOFER: C2.2, J1.1, R2.2
LRCLK0: J7.3, U3.23 (LRCK)
LRCLK1: J8.3, U4.23 (LRCK)
LRCLK2: J9.3, U5.23 (LRCK)
LT_OUT_PRE: R1.1, U3.7 (OUTR)
LW_OUT_PRE: R2.1, U3.6 (OUTL)
MCLK0: J7.1, U3.20 (SCK)
MCLK1: J8.1, U4.20 (SCK)
MCLK2: J9.1, U5.20 (SCK)
unnamed: D1.2 (A), R7.2
unnamed: D2.2 (A), R8.2
unnamed: C17.2, U3.4 (CAPM)
unnamed: C17.1, U3.2 (CAPP)
unnamed: C29.2, C36.1, U3.26 (LDOO)
unnamed: C12.2, U3.5 (VNEG)
unnamed: C19.2, U4.4 (CAPM)
unnamed: C19.1, U4.2 (CAPP)
unnamed: C30.2, C37.1, U4.26 (LDOO)
unnamed: C13.2, U4.5 (VNEG)
unnamed: C21.2, U5.4 (CAPM)
unnamed: C21.1, U5.2 (CAPP)
unnamed: C31.2, C38.1, U5.26 (LDOO)
unnamed: C14.2, U5.5 (VNEG)
RIGHT_TWEETER: C3.2, J2.3, R3.2
RIGHT_WOOFER: C4.2, J2.1, R4.2
RT_OUT_PRE: R3.1, U4.7 (OUTR)
RW_OUT_PRE: R4.1, U4.6 (OUTL)
SCL: J11.1, U3.12 (SCL/MC/ATT1), U4.12 (SCL/MC/ATT1), U5.12 (SCL/MC/ATT1)
SDA: J11.2, U3.11 (SDA/MOSI/ATT2), U4.11 (SDA/MOSI/ATT2), U5.11 (SDA/MOSI/ATT2)
SPARE_OUT: C5.2, J3.3, R5.2
SPARE_OUT_PRE: R5.1, U5.7 (OUTR)
SUBWOOFER: C6.2, R6.2, U1.1
SW_NEG: J4.1, U1.4
SW_OUT: J3.1, J4.2, U1.6
SW_OUT_PRE: R6.1, U5.6 (OUTL)
XSMT: J11.3, U3.25 (XSMT), U4.25 (XSMT), U5.25 (XSMT)

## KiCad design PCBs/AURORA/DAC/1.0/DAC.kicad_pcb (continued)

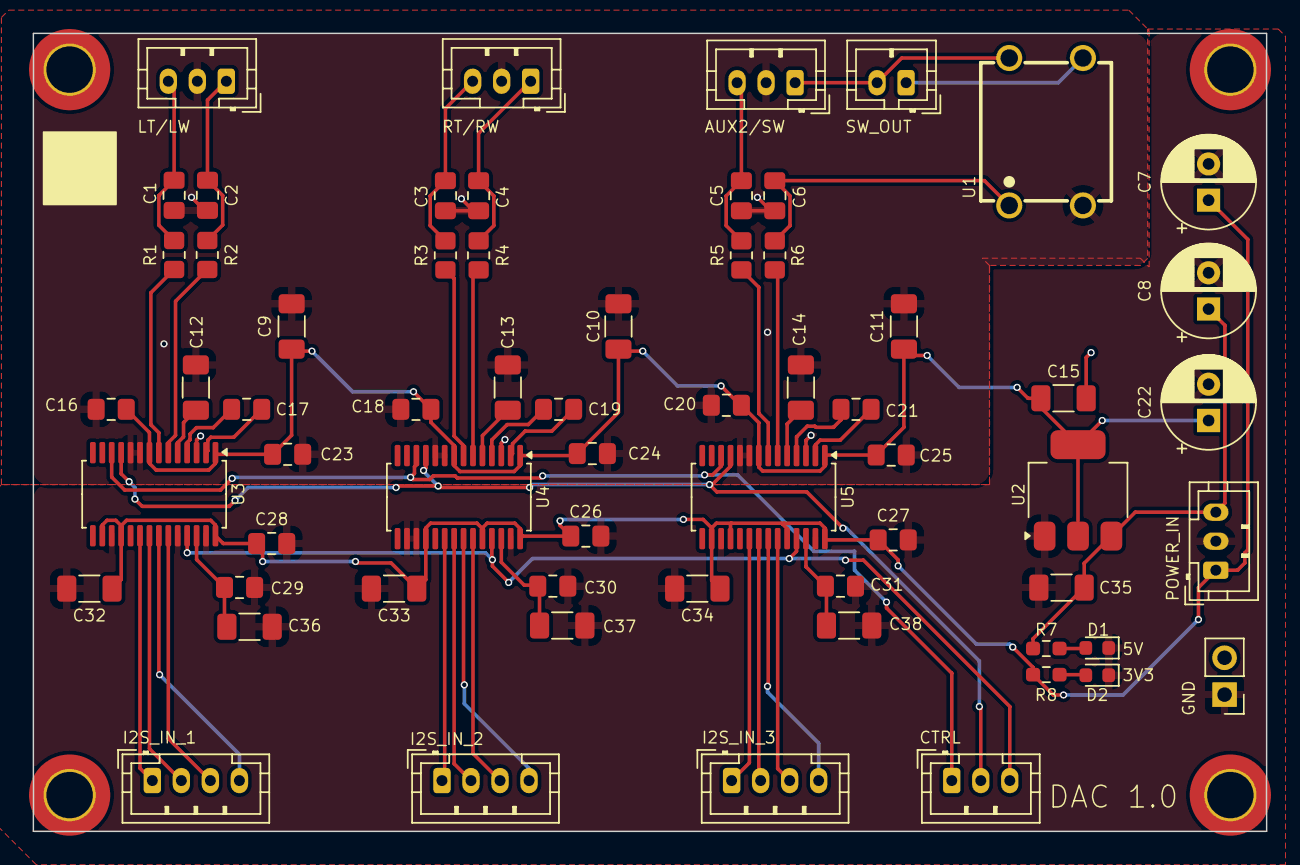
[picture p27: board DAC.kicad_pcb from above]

Board: 2 copper layers, 85.0 x 55.0 mm, 67 parts (0 on the bottom side), 48 nets.

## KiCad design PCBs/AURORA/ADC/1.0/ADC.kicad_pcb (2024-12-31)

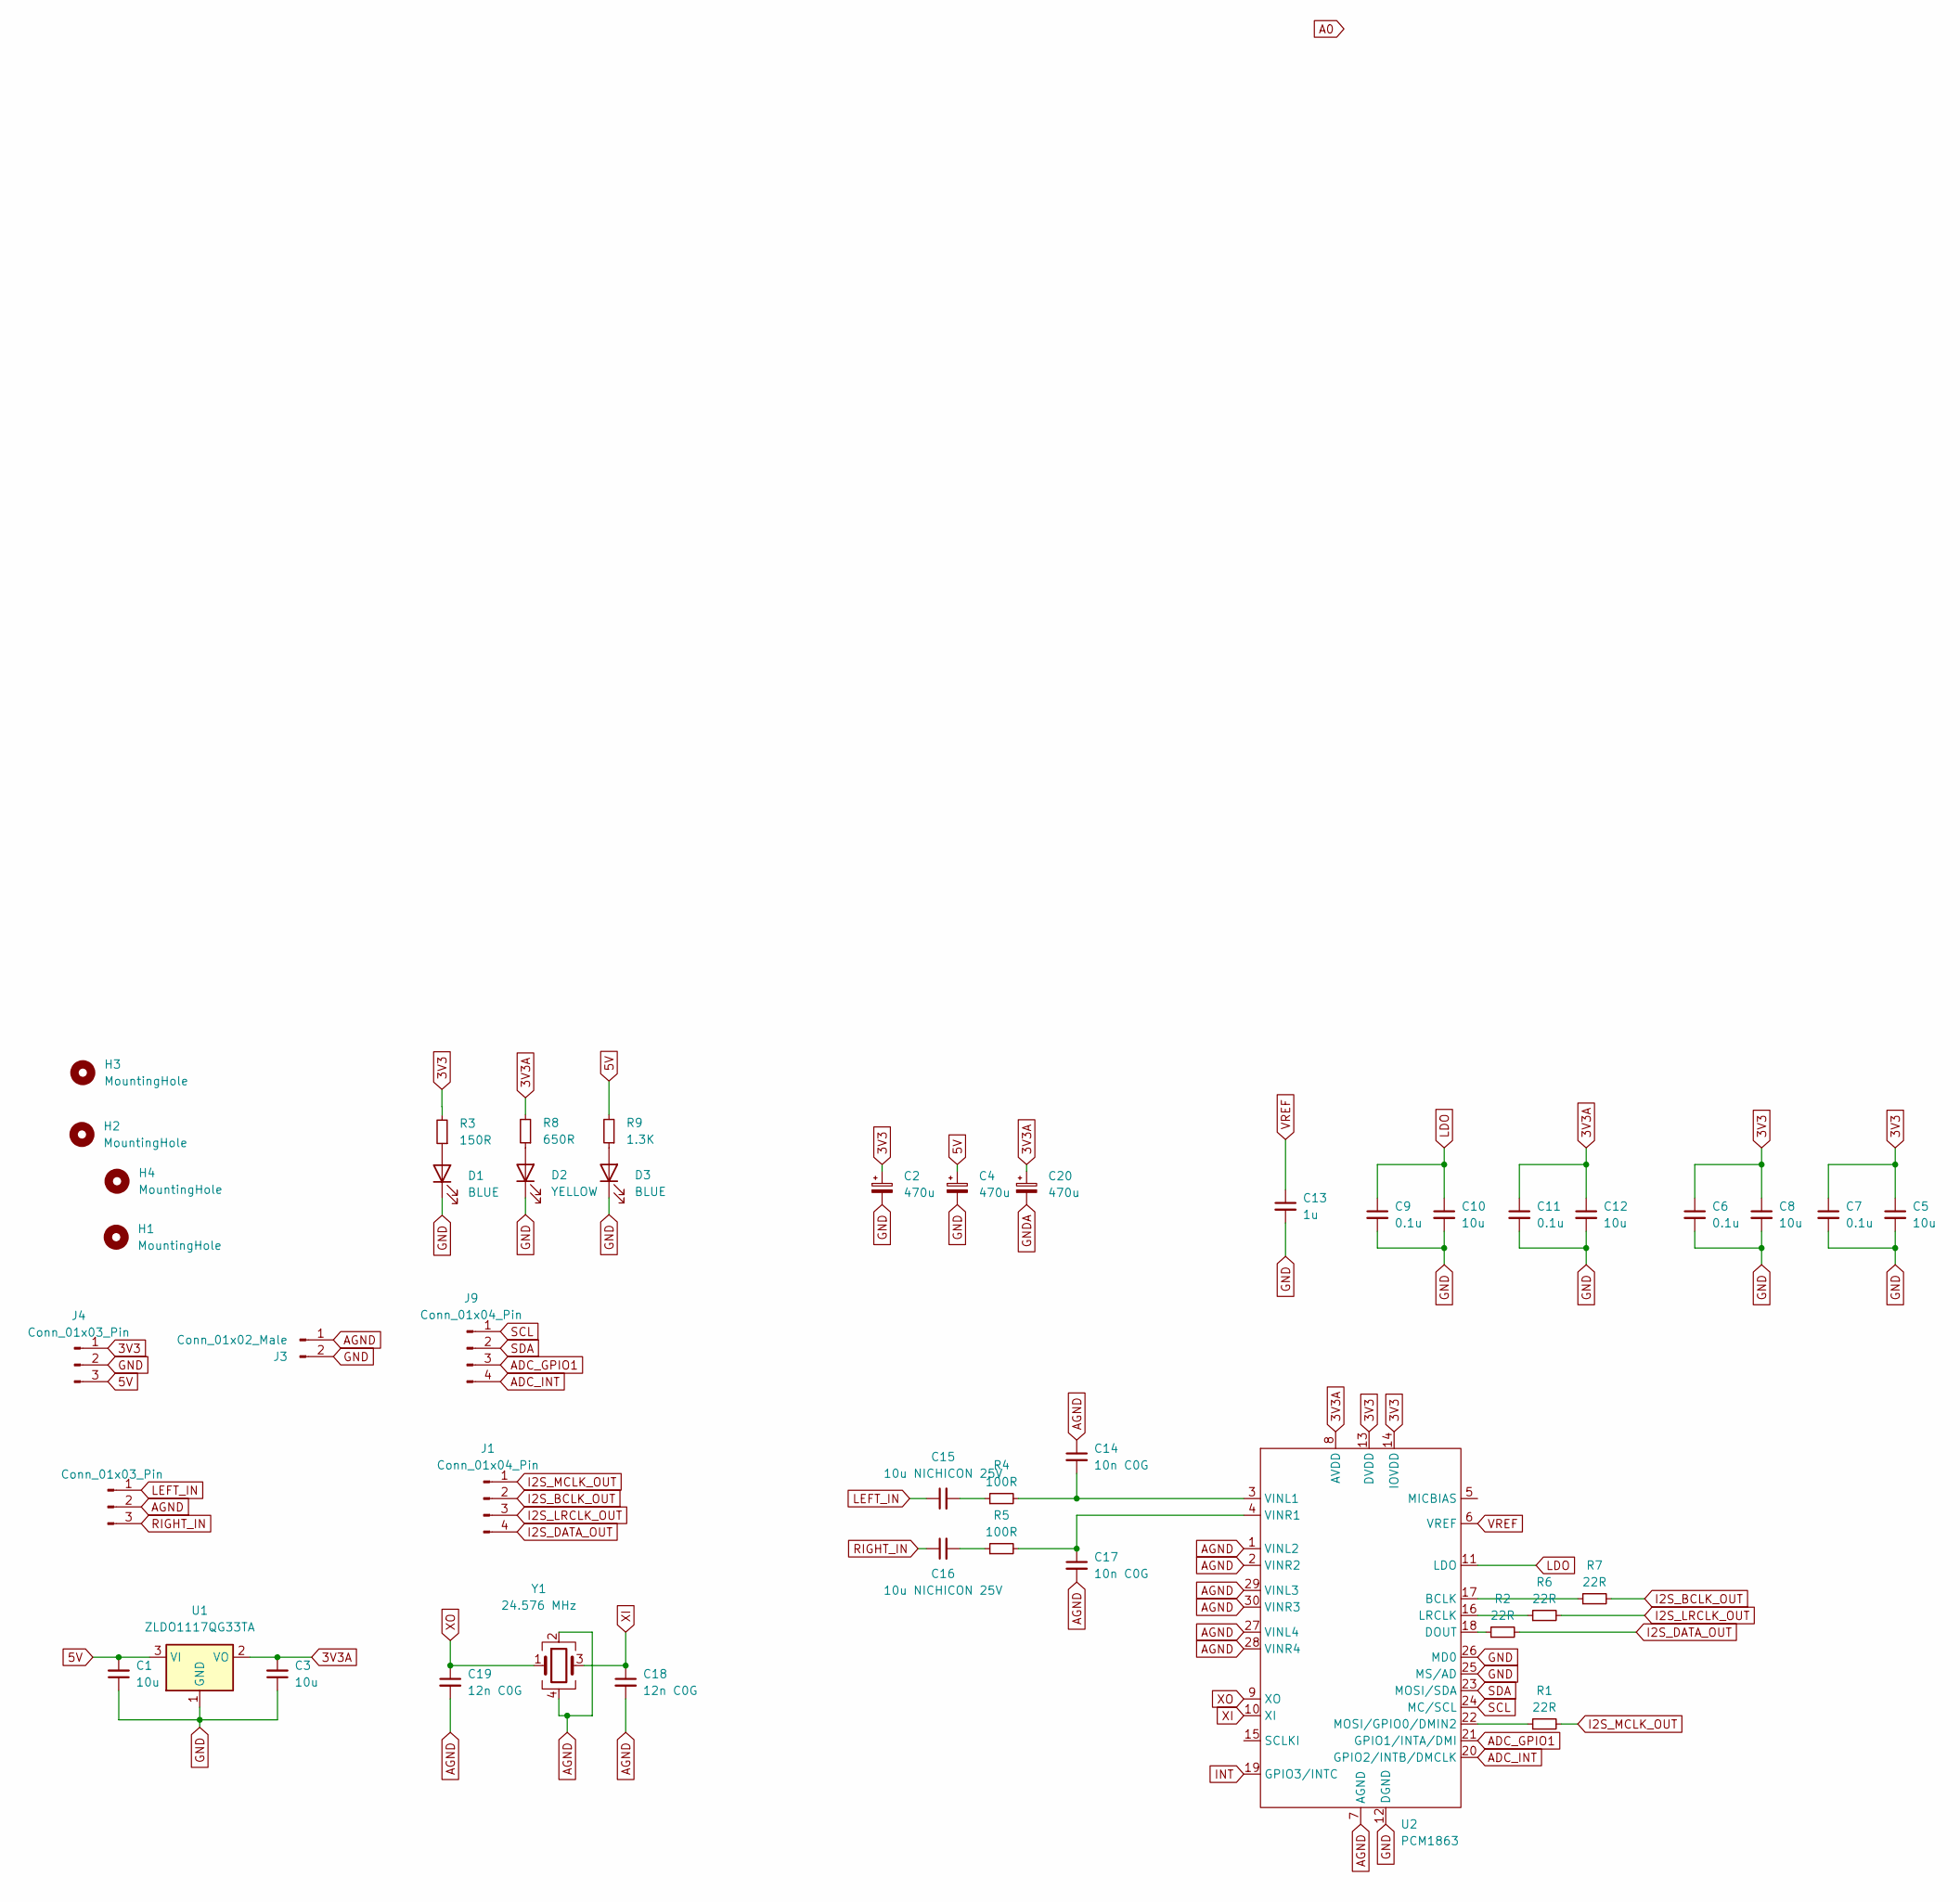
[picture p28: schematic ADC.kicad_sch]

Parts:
C1, C3, C5, C8, C10, C12: 10u; C_1206_3216Metric_Pad1.33x1.80mm_HandSolder
C2, C4, C20: 470u; CP_Radial_D6.3mm_P2.50mm
C6, C7, C9, C11: 0.1u; C_0805_2012Metric_Pad1.18x1.45mm_HandSolder
C13: 1u; C_1206_3216Metric_Pad1.33x1.80mm_HandSolder
C14, C17: 10n C0G; C_0805_2012Metric_Pad1.18x1.45mm_HandSolder; Mouser 791-0805N103G250CT
C15, C16: 10u NICHICON 25V; CP_Radial_D5.0mm_P2.00mm
C18, C19: 12n C0G; C_0805_2012Metric_Pad1.18x1.45mm_HandSolder; Mouser 791-0805N103G250CT
D1, D3: BLUE; LED_0603_1608Metric
D2: YELLOW; LED_0603_1608Metric
H1, H2, H3, H4: MountingHole; MountingHole_3.2mm_M3_DIN965_Pad_TopOnly
J1, J9: Conn_01x04_Pin; JST_PH_B4B-PH-K_1x04_P2.00mm_Vertical
J3: Conn_01x02_Male; PinHeader_1x02_P2.54mm_Vertical
J4, J5: Conn_01x03_Pin; JST_PH_B3B-PH-K_1x03_P2.00mm_Vertical
R1, R2, R6, R7: 22R; R_0805_2012Metric_Pad1.20x1.40mm_HandSolder; Mouser 603-RT0805FRE0722RL
R3: 150R; R_0603_1608Metric_Pad0.98x0.95mm_HandSolder
R4, R5: 100R; R_0805_2012Metric_Pad1.20x1.40mm_HandSolder; Mouser 603-RT0805FRE13100RL
R8: 650R; R_0603_1608Metric_Pad0.98x0.95mm_HandSolder
R9: 1.3K; R_0603_1608Metric_Pad0.98x0.95mm_HandSolder
U1: ZLDO1117QG33TA; SOT-223-3_TabPin2
U2: PCM1863; TSSOP-30_4.4x7.8mm_P0.5mm; Mouser 595-PCM1863DBT
U3: (no value)
Y1: 24.576 MHz; Crystal_SMD_3225-4Pin_3.2x2.5mm

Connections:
3V3: C2.1, C5.1, C6.1, C7.1, C8.1, J4.1, R3.2, U2.13 (DVDD), U2.14 (IOVDD)
3V3A: C3.2, C11.1, C12.1, C20.1, R8.2, U1.2 (VO), U2.8 (AVDD)
5V: C1.2, C4.1, J4.3, R9.2, U1.3 (VI)
ADC_GPIO1: J9.3, U2.21 (GPIO1/INTA/DMI)
ADC_INT: J9.4, U2.20 (GPIO2/INTB/DMCLK)
AGND: C14.1, C17.2, C18.2, C19.2, J3.1, J5.2, U2.1 (VINL2), U2.2 (VINR2), U2.7 (AGND), U2.27 (VINL4), U2.28 (VINR4), U2.29 (VINL3), U2.30 (VINR3), Y1.2, Y1.4
GND: C1.1, C2.2, C3.1, C4.2, C5.2, C6.2, C7.2, C8.2, C9.2, C10.2, C11.2, C12.2, C13.2, D1.1 (K), D2.1 (K), D3.1 (K), J3.2, J4.2, U1.1 (GND), U2.12 (DGND), U2.25 (MS/AD), U2.26 (MD0)
GNDA: C20.2
I2S_BCLK_OUT: J1.2, R7.2
I2S_DATA_OUT: J1.4, R2.2
I2S_LRCLK_OUT: J1.3, R6.2
I2S_MCLK_OUT: J1.1, R1.2
INT: U2.19 (GPIO3/INTC)
LDO: C9.1, C10.1, U2.11 (LDO)
LEFT_IN: C15.1, J5.1
unnamed: C15.2, R4.1
unnamed: C16.2, R5.1
unnamed: D1.2 (A), R3.1
unnamed: D2.2 (A), R8.1
unnamed: D3.2 (A), R9.1
unnamed: R7.1, U2.17 (BCLK)
unnamed: R2.1, U2.18 (DOUT)
unnamed: R6.1, U2.16 (LRCLK)
unnamed: R1.1, U2.22 (MOSI/GPIO0/DMIN2)
unnamed: C14.2, R4.2, U2.3 (VINL1)
unnamed: C17.1, R5.2, U2.4 (VINR1)
RIGHT_IN: C16.1, J5.3
SCL: J9.1, U2.24 (MC/SCL)
SDA: J9.2, U2.23 (MOSI/SDA)
VREF: C13.1, U2.6 (VREF)
XI: C18.1, U2.10 (XI), Y1.3
XO: C19.1, U2.9 (XO), Y1.1

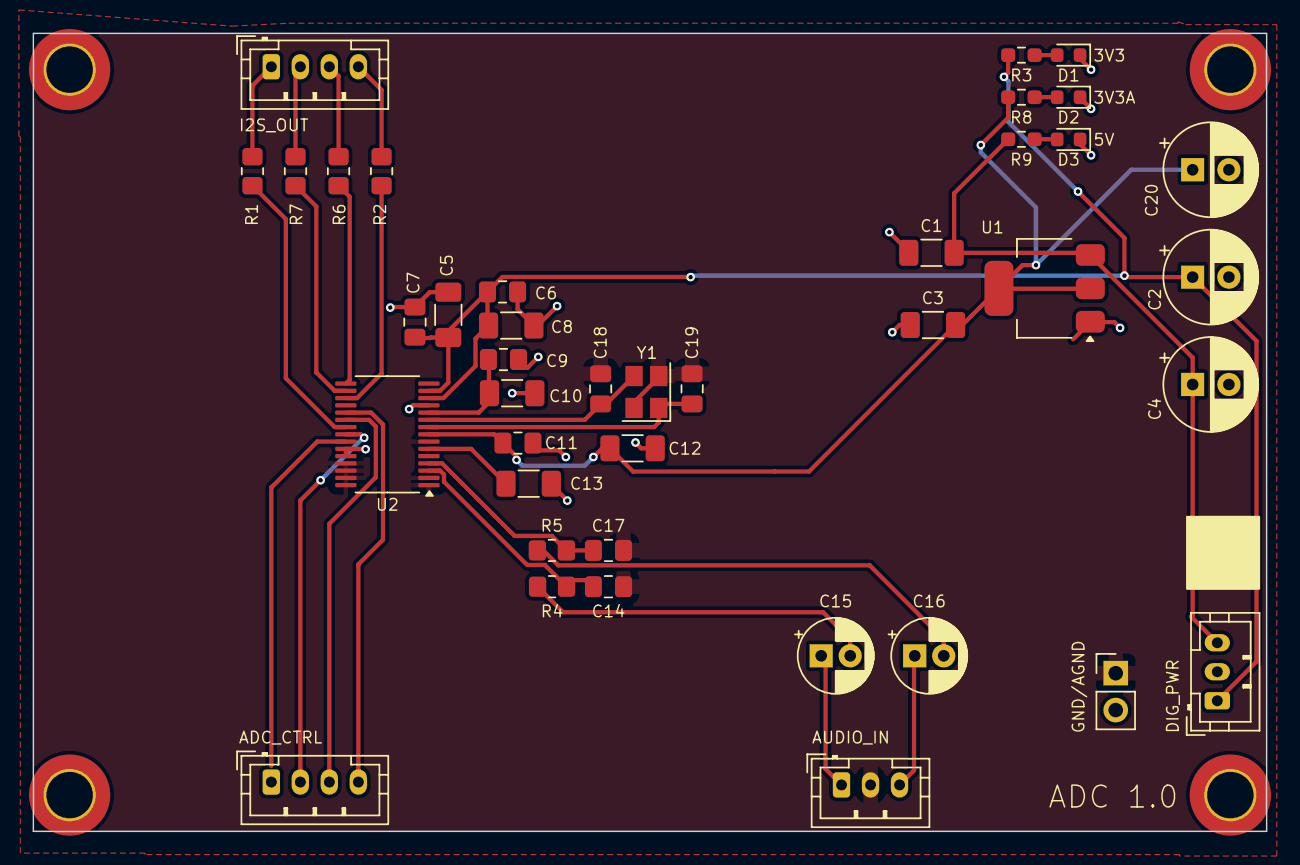
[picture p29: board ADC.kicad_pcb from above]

Board: 2 copper layers, 85.0 x 55.0 mm, 44 parts (0 on the bottom side), 30 nets.

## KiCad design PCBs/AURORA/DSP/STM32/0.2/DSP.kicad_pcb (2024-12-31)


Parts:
C1, C2, C10, C11, C13: 10u; C_1206_3216Metric; LCSC C13585
C3, C4, C5, C9, C14, C16, C17, C19, C22, C24, C29: 0.1u; C_0805_2012Metric; LCSC C28233
C6, C18, C21: 220u; CP_Elec_6.3x7.7; LCSC C4747974
C7, C8: 20p; C_0805_2012Metric; LCSC C1798
C12, C15: 2.2u; C_1206_3216Metric; LCSC C50254
D1, D2, D3, D4, D5, D6, D7, D8: BLUE; D_0603_1608Metric; LCSC C84259
H1, H2, H3, H4: MountingHole; MountingHole_3.2mm_M3_DIN965_Pad_TopOnly
J1, J2, J3, J4, J7: Conn_01x04_Pin; JST_PH_B4B-PH-K_1x04_P2.00mm_Vertical
J5: Conn_01x06_Pin; PinHeader_1x06_P2.54mm_Vertical; LCSC C6332199
J6: Conn_01x03_Pin; JST_PH_B3B-PH-K_1x03_P2.00mm_Vertical
J8: Conn_01x03_Pin; PinHeader_1x03_P2.54mm_Vertical
J9: Conn_01x02_Male; JST_PH_B2B-PH-K_1x02_P2.00mm_Vertical
J11, J14, J15, J17: Conn_01x02_Pin; PinHeader_1x02_P2.54mm_Vertical; LCSC C225477
J13, J18: Conn_01x04_Pin; PinHeader_1x04_P2.54mm_Vertical; LCSC C6332197
J19: Conn_01x05_Pin; JST_PH_B5B-PH-K_1x05_P2.00mm_Vertical
R1, R2, R19, R22, R23, R24, R25, R26: 150R; R_0603_1608Metric; LCSC C22808
R3, R4, R5, R6, R7, R8, R9, R10, R11, R12, R13, R14, R15, R16, R17, R18: 22R; R_0603_1608Metric; LCSC C23345
R20, R21, R27, R28: 4.7K; R_0603_1608Metric; LCSC C23162
SW2: TS-1187A-B-A-B; SW-SMD_4P-L5.1-W5.1-P3.70-LS6.5-TL_H1.5; LCSC Part C318884
U1: AMS1117-3.3; SOT-223-3_TabPin2; LCSC C6186
U2, U3, U4: PI6CV304; TSSOP-8_4.4x3mm_P0.65mm; Mouser 729-PI6CV304LEX
U5: STM32H723VGTx; LQFP-100_14x14mm_P0.5mm; LCSC C730142
U6: ESP32-WROOM-32U
Y1: 25 MHz; Crystal_SMD_SeikoEpson_FA238-4Pin_3.2x2.5mm; Mouser 520-240-8-33B2CKMTR3

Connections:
3V3: C3.1, C4.1, C5.1, C10.1, C17.1, C19.1, C21.1, C22.1, C24.1, C29.1, J5.1, J6.1, J14.1, R2.1, R21.1, R28.2, U2.6 (VDD), U3.6 (VDD), U4.6 (VDD), U5.6 (VBAT), U5.11 (VDD), U5.27 (VDD), U5.50 (VDD), U5.75 (VDD), U5.100 (VDD)
3V3A: C1.1, C6.1, C13.2, C14.2, R19.1, U1.2 (VO), U5.21 (VDDA)
5V: C2.1, C18.1, J6.3, J14.2, R1.1, U1.3 (VI)
ADC: J17.2, U5.30 (PA6)
AGND: C13.1, C14.1, J11.2, U5.19 (VSSA)
BOOT0: J19.4, R27.2, U5.94 (BOOT0)
CLOCKS_EN: R20.2, U2.2 (OE), U3.2 (OE), U4.2 (OE), U5.9 (PC15)
DAC: J17.1, U5.28 (PA4)
DSP_ACTIVE: R26.1, U5.51 (PB12)
DSP_INT: J19.5, R28.1, U5.81 (PD0)
DSP_NRST: C16.1, J5.5, J19.3, R21.2, SW2.1 (A), SW2.2 (B), U5.14 (NRST)
EXT1: J18.1, U5.86 (PD5)
EXT2: J18.2, U5.87 (PD6)
EXT3: J18.3, U5.88 (PD7)
EXT4: J18.4, U5.91 (PB5)
GND: C3.2, C4.2, C5.2, C6.2, C7.2, C8.2, C9.1, C10.2, C11.2, C12.2, C15.2, C16.2, C17.2, C18.2, C19.2, C21.2, C22.2, C24.2, C29.2, D1.1 (K), D2.1 (K), D3.1 (K), D4.1 (K), D5.1 (K), D6.1 (K), D7.1 (K), D8.1 (K), J5.3, J6.2, J11.1, R20.1, R27.1, SW2.3 (C), SW2.4 (D), U2.4 (GND), U3.4 (GND), U4.4 (GND), U5.10 (VSS), U5.26 (VSS), U5.49 (VSS), U5.74 (VSS), U5.99 (VSS), Y1.2, Y1.4
I2S_IN_BCLK: J7.2, U2.1 (CLK_IN), U5.4 (PE5), U5.29 (PA5)
I2S_IN_DATA: J7.4, U5.90 (PB4(NJTRST))
I2S_IN_LRCLK: J7.3, U3.1 (CLK_IN), U5.3 (PE4), U5.77 (PA15(JTDI))
I2S_IN_MCLK: J7.1, U5.66 (PC9)
I2S_OUT_1_DATA: J1.4, J13.4, R14.2
I2S_OUT_2_DATA: J2.4, R10.2
I2S_OUT_3_DATA: J3.4, R6.2
I2S_OUT_4_DATA: J4.4, R18.2
I2S_OUT_BCLK1: J1.2, J13.2, R4.2
I2S_OUT_BCLK2: J2.2, R8.2
I2S_OUT_BCLK3: J3.2, R12.2
I2S_OUT_BCLK4: J4.2, R16.2
I2S_OUT_LRCLK1: J1.3, J13.3, R5.2
I2S_OUT_LRCLK2: J2.3, R9.2
I2S_OUT_LRCLK3: J3.3, R13.2
I2S_OUT_LRCLK4: J4.3, R17.2
I2S_OUT_MCLK: U4.1 (CLK_IN)
I2S_OUT_MCLK1: J1.1, J13.1, R3.2
I2S_OUT_MCLK2: J2.1, R7.2
I2S_OUT_MCLK3: J3.1, R11.2
I2S_OUT_MCLK4: J4.1, R15.2
unnamed: C12.1, U5.48 (VCAP)
unnamed: C15.1, U5.73 (VCAP)
unnamed: D1.2 (A), R1.2
unnamed: D2.2 (A), R2.2
unnamed: D3.2 (A), R19.2
unnamed: D4.2 (A), R22.2
unnamed: D5.2 (A), R23.2
unnamed: D6.2 (A), R24.2
unnamed: D7.2 (A), R25.2
unnamed: D8.2 (A), R26.2
unnamed: C1.2, C2.2, U1.1 (GND)
unnamed: R4.1, U2.3 (OUT1)
unnamed: R8.1, U2.5 (OUT2)
unnamed: R12.1, U2.8 (OUT3)
unnamed: R16.1, U2.7 (OUT4)
unnamed: R5.1, U3.3 (OUT1)
unnamed: R9.1, U3.5 (OUT2)
unnamed: R13.1, U3.8 (OUT3)
unnamed: R17.1, U3.7 (OUT4)
unnamed: R3.1, U4.3 (OUT1)
unnamed: R7.1, U4.5 (OUT2)
unnamed: R11.1, U4.8 (OUT3)
unnamed: R15.1, U4.7 (OUT4)
unnamed: R14.1, U5.31 (PA7)
unnamed: R18.1, U5.16 (PC1)
unnamed: R6.1, U5.2 (PE3)
unnamed: R10.1, U5.5 (PE6)
unnamed: C9.2, C11.1, U5.20 (VREF+)
unnamed: U6.1 (GND), U6.15 (GND), U6.38 (GND), U6.39 (GND)
OSC_IN: C7.1, U5.12 (PH0), Y1.3
OSC_OUT: C8.1, U5.13 (PH1), Y1.1
PROCESS_FOUR: R25.1, U5.85 (PD4)
PROCESS_LEFT: R22.1, U5.82 (PD1)
PROCESS_RIGHT: R23.1, U5.83 (PD2)
PROCESS_SW: R24.1, U5.84 (PD3)
SCL: J19.1, U5.92 (PB6)
SDA: J19.2, U5.93 (PB7)
SPI_CLK: J8.3, U5.46 (PB10)
SPI_MISO: J8.1, U5.17 (PC2_C)
SPI_MOSI: J8.2, U5.18 (PC3_C)
SWCLK: J5.2, U5.76 (PA14(JTCK)
SWDIO: J5.4, U5.72 (PA13(JTMS)
SWO: J5.6, U5.89 (PB3(JTDO)
UART1_RX: J9.2, J15.1, U5.53 (PB14)
UART1_TX: J9.1, J15.2, U5.54 (PB15)


Board: 4 copper layers, 85.0 x 55.0 mm, 87 parts (0 on the bottom side), 81 nets.

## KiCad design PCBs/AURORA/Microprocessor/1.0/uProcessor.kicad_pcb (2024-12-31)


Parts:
C1, C7: 10N; C_0805_2012Metric_Pad1.18x1.45mm_HandSolder
C2: 10U; C_1206_3216Metric_Pad1.33x1.80mm_HandSolder
C3, C4, C6: 0.1U; C_0805_2012Metric_Pad1.18x1.45mm_HandSolder
C5: 100n; C_0805_2012Metric_Pad1.18x1.45mm_HandSolder
C8, C13: 10V 220u; CP_Radial_D6.3mm_P2.50mm
C9, C10, C11, C12: 10N; C_0603_1608Metric_Pad1.08x0.95mm_HandSolder
D1: RED; LED_0603_1608Metric; LCSC XL-1608UBC-04
D2: BLUE; LED_0603_1608Metric; LCSC NCD0603R1
H1, H2, H3, H4: MountingHole; MountingHole_3.2mm_M3_DIN965_Pad_TopOnly
J1, J7, J8, J10, J11, J12, J16, J18, J19: Conn_01x02_Male; JST_PH_B2B-PH-K_1x02_P2.00mm_Vertical
J2, J14, J17: Conn_01x05_Pin; JST_PH_B5B-PH-K_1x05_P2.00mm_Vertical
J3, J6, J15: Conn_01x04_Pin; JST_PH_B4B-PH-K_1x04_P2.00mm_Vertical
J4, J13: Conn_01x03_Pin; JST_PH_B3B-PH-K_1x03_P2.00mm_Vertical
J5, J9: Conn_01x02_Male; PinHeader_1x02_P2.54mm_Vertical
Q1, Q2: BC817; TSOT-23; Mouser 637-BC817K-40
R1, R8, R9, R16, R21: 4.7K; R_0603_1608Metric_Pad0.98x0.95mm_HandSolder
R2, R3, R4, R5: 22R; R_0603_1608Metric; Mouser 603-RT0805FRE0722RL
R6: 1000R; R_0603_1608Metric_Pad0.98x0.95mm_HandSolder
R7, R24: 150R; R_0603_1608Metric_Pad0.98x0.95mm_HandSolder
R10, R13, R14, R15: 10K; R_0603_1608Metric_Pad0.98x0.95mm_HandSolder
R11: 700R; R_0603_1608Metric_Pad0.98x0.95mm_HandSolder
R12, R23: 1K; R_0603_1608Metric_Pad0.98x0.95mm_HandSolder
R17, R18, R19, R20: 50K; R_0603_1608Metric_Pad0.98x0.95mm_HandSolder
R22: 75R; R_0603_1608Metric_Pad0.98x0.95mm_HandSolder
SD1: TF-115-BCP9; TF-SMD_TF-115-BCP9; LCSC Part C720505
U1: TMP100; SOT-23-6
U3: TCA9517DR; SOIC-8_3.9x4.9mm_P1.27mm; Mouser 595-TCA9517DR
U4: ESP32-S3-WROOM-1

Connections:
3V3: C1.1, C2.1, C5.1, C6.1, C7.2, C13.1, J4.2, J5.1, J13.1, J14.2, J17.2, R7.1, R8.1, R10.1, R13.1, R16.1, R17.2, R18.1, R19.1, R20.1, SD1.4 (VDD), U1.4 (V+), U3.1 (VCCA), U3.5 (EN), U4.2 (3V3)
5V: C4.1, C8.1, J13.3, J15.2, R6.1, R11.2, R14.1, R15.1, R22.2, U3.8 (VCCB)
BACKLIGHT: R21.1, R23.1, U4.22 (GPIO14/TOUCH14/ADC2_CH3/FSPIWP/FSPIDQS/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)
BOOT: J6.4, J9.1, R16.2, U4.27 (GPIO0/BOOT)
DONTUSE3: U4.26 (GPIO45)
DONTUSE4: U4.16 (GPIO46)
ENABLE: C3.2, J1.2, J6.3, R8.2, U4.3 (EN)
FROM_BACKLIGHT: J16.2, Q2.3 (C)
FROM_POWER_LED: J7.2, Q1.3 (C)
GND: C1.2, C2.2, C3.1, C4.2, C5.2, C6.2, C7.1, C8.2, C9.1, C10.1, C11.1, C12.1, C13.2, D1.1 (K), D2.1 (K), J1.1, J4.1, J9.2, J10.1, J13.2, J14.1, J15.1, J17.1, J18.1, Q1.2 (E), Q2.2 (E), R1.1, R9.2, R21.2, SD1.6 (VSS), SD1.10 (GND), SD1.11 (GND), SD1.12 (GND), SD1.13 (GND), U1.2 (GND), U1.3 (ADD1), U1.5 (ADD0), U3.4 (GND), U4.1 (GND), U4.40 (GND), U4.41 (GND)
GPIO_INTA: J2.3, U4.4 (GPIO4/TOUCH4/ADC1_CH3)
GPIO_INTB: J2.4, U4.5 (GPIO5/TOUCH5/ADC1_CH4)
GPIO_RESET: J2.5, R1.2, U4.6 (GPIO6/TOUCH6/ADC1_CH5)
HARD_RESET: J5.2, R9.1, U4.7 (GPIO7/TOUCH7/ADC1_CH6)
I2S_BCLK: J3.2, R4.2
I2S_DATA: J3.4, R2.2
I2S_LRCLK: J3.3, R3.2
I2S_MCLK: J3.1, R5.2
INPUT_BUTTON: J17.5, U4.25 (GPIO48/SPICLK_N/SUBSPICLK_N_DIFF)
INPUT_CH1: C11.2, J17.3, U4.23 (GPIO21)
INPUT_CH2: C12.2, J17.4, U4.24 (GPIO47/SPICLK_P/SUBSPICLK_P_DIFF)
IR_RECV: J4.3, U4.8 (GPIO15/U0RTS/ADC2_CH4/XTAL_32K_P)
unnamed: D1.2 (A), R6.2
unnamed: D2.2 (A), R7.2
unnamed: J18.2, R24.2
unnamed: Q1.1 (B), R12.2
unnamed: Q2.1 (B), R23.2
unnamed: R2.1, U4.39 (GPIO1/TOUCH1/ADC1_CH0)
unnamed: R3.1, U4.38 (GPIO2/TOUCH2/ADC1_CH1)
unnamed: R5.1, U4.34 (MTDI/GPIO41/CLK_OUT1)
unnamed: R4.1, U4.35 (MTMS/GPIO42)
POWER_BUTTON: J10.2, U4.10 (GPIO17/U1TXD/ADC2_CH6)
POWER_LED: R12.1, U4.9 (GPIO16/U0CTS/ADC2_CH5/XTAL_32K_N)
RX: J6.1, U4.36 (U0RXD/GPIO44/CLK_OUT2)
RX2: J19.2, U4.30 (SPIDQS/GPIO37/FSPIQ/SUBSPIQ)
SCL: J2.1, J11.1, J12.1, R10.2, U1.1 (SCL), U3.2 (SCLA), U4.33 (MTDO/GPIO40/CLK_OUT2)
SCL_5V: J8.1, J15.4, R15.2, U3.7 (SCLB)
SDA: J2.2, J11.2, J12.2, R13.2, U1.6 (SDA), U3.3 (SDAA), U4.32 (MTCK/GPIO39/CLK_OUT3/SUBSPICS1)
SDA_5V: J8.2, J15.3, R14.2, U3.6 (SDAB)
SD_CD: R17.1, SD1.9 (CD), U4.11 (GPIO18/U1RXD/ADC2_CH7/CLK_OUT3)
SPI_CLK: SD1.5 (CLK), U4.18 (GPIO10/TOUCH10/ADC1_CH9/FSPICS0/FSPIIO4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)
SPI_CS: R20.2, SD1.2 (CD/DATA3), U4.17 (GPIO9/TOUCH9/ADC1_CH8/FSPIHD/SUBSPIHD)
SPI_MISO: R18.2, SD1.7 (DAT0), U4.12 (GPIO8/TOUCH8/ADC1_CH7/SUBSPICS1)
SPI_MOSI: R19.2, SD1.3 (CMD), U4.15 (GPIO3/TOUCH3/ADC1_CH2)
STANDBY_LED: R24.1, U4.28 (SPIIO6/GPIO35/FSPID/SUBSPID)
TO_BACKLIGHT: J16.1, R22.1
TO_POWER_LED: J7.1, R11.1
TX: J6.2, U4.37 (U0TXD/GPIO43/CLK_OUT1)
TX2: J19.1, U4.29 (SPIIO7/GPIO36/FSPICLK/SUBSPICLK)
USB_D+: U4.14 (GPIO20/U1CTS/ADC2_CH9/CLK_OUT1/USB_D+)
USB_D-: U4.13 (GPIO19/U1RTS/ADC2_CH8/CLK_OUT2/USB_D-)
VOL_BUTTON: J14.5, U4.21 (GPIO13/TOUCH13/ADC2_CH2/FSPIQ/FSPIIO7/S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)
VOL_CH1: C9.2, J14.3, U4.19 (GPIO11/TOUCH11/ADC2_CH0/FSPID/FSPIIO5/S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)
VOL_CH2: C10.2, J14.4, U4.20 (GPIO12/TOUCH12/ADC2_CH1/FSPICLK/FSPIIO6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)


Board: 2 copper layers, 85.0 x 55.0 mm, 68 parts (0 on the bottom side), 50 nets.

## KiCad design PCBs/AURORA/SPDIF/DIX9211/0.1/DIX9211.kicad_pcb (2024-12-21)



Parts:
C1, C2, C3, C4: 10n C0G; C_0805_2012Metric_Pad1.18x1.45mm_HandSolder; Mouser 791-0805N103G250CT
C5, C8, C13, C14: 0.1u; C_0805_2012Metric_Pad1.18x1.45mm_HandSolder
C6, C7, C15, C16, C20: 10u; C_1206_3216Metric_Pad1.33x1.80mm_HandSolder
C9, C11, C12: 68n C0G; C_0603_1608Metric
C10: 4.7n C0G; C_0603_1608Metric
C17, C18, C19: 220u; CP_Radial_D6.3mm_P2.50mm
D1, D3: YELLOW; LED_0603_1608Metric
D2: BLUE; LED_0603_1608Metric
H1, H2, H3, H4: MountingHole; MountingHole_3.2mm_M3_DIN965_Pad_TopOnly
J1, J2, J3, J4, J5: Conn_01x02_Pin; JST_XH_B2B-XH-A_1x02_P2.50mm_Vertical
J6, J7, J11: Conn_01x04_Pin; JST_PH_B4B-PH-K_1x04_P2.00mm_Vertical
J8: Conn_01x04_Pin; PinHeader_1x04_P2.54mm_Vertical
J9, J13: Conn_01x02_Pin; PinHeader_1x02_P2.54mm_Vertical
J10: Conn_01x05_Pin; JST_PH_B5B-PH-K_1x05_P2.00mm_Vertical
J12: Conn_01x03_Pin; JST_PH_B3B-PH-K_1x03_P2.00mm_Vertical
R1, R2, R3, R4: 75R; R_0603_1608Metric_Pad0.98x0.95mm_HandSolder; Mouser 71-CRCW0603-75-E3
R5, R19: 325R; R_0603_1608Metric_Pad0.98x0.95mm_HandSolder
R6, R9: 220R; R_0603_1608Metric_Pad0.98x0.95mm_HandSolder; Mouser 71-CRCW0603-75-E3
R7, R8: 100K; R_0603_1608Metric_Pad0.98x0.95mm_HandSolder; Mouser 71-CRCW0603-75-E3
R10: 200R; R_0603_1608Metric
R11: 680R; R_0603_1608Metric
R12, R16: 4.7K; R_0603_1608Metric
R13, R14, R15, R17: 22R; R_0603_1608Metric
R18: 500R; R_0603_1608Metric_Pad0.98x0.95mm_HandSolder
U1, U2, U3, U4: DA101C_C6931652; XFMR-TH_4P-L9.5-W9.0-P5.08-LS10.2_C9900096976; LCSC Part C6931652
U5: 74HC7014; TSSOP-14_4.4x5mm_P0.65mm
U6: DIX9211; LQFP-48_7x7mm_P0.5mm; Mouser 595-DIX9211PTR
U7: AMS1117-3.3; SOT-223-3_TabPin2
Y1: 24.576MHz; Crystal_SMD_SeikoEpson_FA238-4Pin_3.2x2.5mm

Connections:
3V3: C5.2, C6.2, C14.2, C15.2, C19.1, D3.2 (A), J9.2, J12.1, U5.14 (VCC), U6.22 (DVDD)
3V3A: C7.2, C8.2, C13.2, C16.2, C17.1, D1.2 (A), U6.36 (VDDRX), U6.42 (VCC), U7.2 (VO)
5V: C18.1, C20.2, D2.2 (A), J12.3, U7.3 (VI)
ADR0: J9.1, R12.2, U6.23 (MDO/ADR0)
AGND: C9.2, C10.1, C11.1, C12.2, J13.2, R1.2, R2.2, R3.2, R4.2, U1.4, U2.4, U3.4, U4.4, U6.38 (GNDRX), U6.41 (AGND), Y1.2, Y1.4
GND: C5.1, C6.1, C7.1, C8.1, C13.1, C14.1, C15.1, C16.1, C17.2, C18.2, C19.2, C20.1, J5.2, J12.2, J13.1, R5.1, R12.1, R16.1, R18.1, R19.1, U5.7 (GND), U6.21 (DGND), U6.26 (MS/ADDR1), U6.27 (MODE), U6.45 (RSV1), U6.46 (RSV1), U7.1 (GND)
I2S_BCLK: J8.2, J11.2, R14.2
I2S_DATA: J8.4, J11.4, R17.2
I2S_IN_BCLK_1: J6.2, U6.8 (MPIO_C1)
I2S_IN_BCLK_2: J7.2, U6.12 (MPIO_B1)
I2S_IN_DATA_1: J6.4, U6.10 (MPIO_C3)
I2S_IN_DATA_2: J7.4, U6.14 (MPIO_B3)
I2S_IN_LRCLK_1: J6.3, U6.9 (MPIO_C2)
I2S_IN_LRCLK_2: J7.3, U6.13 (MPIO_B2)
I2S_IN_SCLK_1: J6.1, U6.7 (MPIO_C0)
I2S_IN_SCLK_2: J7.1, U6.11 (MPIO_B0)
I2S_LRCLK: J8.3, J11.3, R15.2
I2S_SCLK: J8.1, J11.1, R13.2
unnamed: C1.2, R1.1, U1.6
unnamed: C2.2, R2.1, U2.6
unnamed: C3.1, R6.1
unnamed: C3.2, R3.1, U3.6
unnamed: C4.1, R9.1
unnamed: C4.2, R4.1, U4.6
unnamed: C9.1, R10.1, Y1.3
unnamed: C11.2, R11.2
unnamed: D1.1 (K), R5.2
unnamed: D2.1 (K), R18.2
unnamed: D3.1 (K), R19.2
unnamed: R6.2, R7.1, U5.1
unnamed: R7.2, U5.2, U5.3
unnamed: R8.1, R9.2, U5.5
unnamed: R8.2, U5.6, U5.9
unnamed: R14.1, U6.19 (BCLK)
unnamed: R17.1, U6.17 (DOUT)
unnamed: C10.2, R11.1, U6.43 (FILT)
unnamed: R15.1, U6.18 (LRCLK)
unnamed: R13.1, U6.20 (SCLKO)
SCL: J10.1, U6.25 (MC/SCL)
SDA: J10.2, U6.24 (MDI/SDA)
SPDIF1_GND: J1.2, U1.3
SPDIF1_IN: J1.1, U1.1
SPDIF2_GND: J2.2, U2.3
SPDIF2_IN: J2.1, U2.1
SPDIF3_GND: J3.2, U3.3
SPDIF3_IN: J3.1, U3.1
SPDIF4_GND: J4.2, U4.3
SPDIF4_IN: J4.1, U4.1
SPDIF_1: C1.1, U6.37 (RXIN0)
SPDIF_2: C2.1, U6.35 (RXIN1)
SPDIF_3: U5.4, U6.33 (RXIN2)
SPDIF_4: U5.8, U6.32 (RXIN3)
SPDIF_INT0: J10.3, U6.1 (ERROR/INT0)
SPDIF_INT1: J10.4, U6.2 (NPCM/INT1)
SPDIF_OUT: U6.6 (MPIO_A3), U6.15 (MPO0)
SPDIF_RESET: J10.5, R16.2, U6.34 (/RESET)
TOSLINK_IN: J5.1, U6.3 (MPIO_A0)
XTI: C12.1, U6.39 (XTI), Y1.1
XTO: R10.2, U6.40 (XTO)

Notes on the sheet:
OUTPUTS
INPUTS


Board: 4 copper layers, 85.0 x 55.0 mm, 67 parts (0 on the bottom side), 59 nets.

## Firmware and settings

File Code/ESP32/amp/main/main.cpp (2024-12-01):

#include <stdio.h>
#include <driver/i2c.h>
#include "freertos/FreeRTOS.h"
#include "freertos/task.h"
#include "sdkconfig.h"
#include "esp_system.h"
#include "esp_wifi.h" 
#include "esp_event.h" 
#include "esp_log.h"
#include "nvs_flash.h"

// Our amplifier files
#include "amplifier.h"
#include "wifi.h"

// Main Display Thread
void 
startDisplayThread( void *param ) {
    // Proxy thread start to main amplifier thread
    ((Amplifier *)param)->handleDisplayThread();
}

// Main Amplifier Thread
void 
startAudioThread( void *param ) {
    // Proxy thread start to main amplifier thread
    ((Amplifier *)param)->handleAudioThread();
}

void
startRadioThread( void *param ) {
    // Proxy thread start to main radio thread
    ((Amplifier *)param)->handleRadioThread();
}

void
startTimerThread( void *param ) {
    // Proxy thread start to main radio thread
    ((Amplifier *)param)->handleTimerThread();
}

void
startAmplifierThread( void *param ) {
    // Proxy thread start to main radio thread
    ((Amplifier *)param)->handleAmplifierThread();
}

extern "C" void app_main(void)
{
    Amplifier *amp = new Amplifier;
    amp->init();

    xTaskCreate(
        startTimerThread,
        "Timer Thread",
        10000,
        (void *)amp,
        2,
        NULL
    );   

    xTaskCreate(
        startDisplayThread,
        "Display Thread",
        10000,
        (void *)amp,
        2,
        NULL
    );

    xTaskCreate(
        startAudioThread,
        "Audio Thread",
        10000,
        (void *)amp,
        2,
        NULL
    );

    xTaskCreate(
        startRadioThread,
        "Radio Thread",
        10000,
        (void *)amp,
        2,
        NULL
    ); 

    xTaskCreate(
        startAmplifierThread,
        "Amplifier Thread",
        10000,
        (void *)amp,
        3,
        NULL
    );   

    while ( true ) {
        vTaskDelay( 1000 / portTICK_PERIOD_MS );
    }
}

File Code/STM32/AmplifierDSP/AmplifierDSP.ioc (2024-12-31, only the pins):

Mcu.UserName=STM32H723VGTx
PA13(JTMS/SWDIO).Signal=DEBUG_JTMS-SWDIO
PA14(JTCK/SWCLK).Signal=DEBUG_JTCK-SWCLK
PA15(JTDI).Signal=I2S1_WS
PA4.Signal=COMP_DAC11_group
PA5.Signal=I2S1_CK
PA6.Signal=ADCx_INP3
PA7.Signal=I2S1_SDO
PB10.Signal=SPI2_SCK
PB12.GPIO_Label=DSP_ACTIVE
PB12.Signal=GPIO_Output
PB14.Signal=USART1_TX
PB15.Signal=USART1_RX
PB3(JTDO/TRACESWO).Signal=DEBUG_JTDO-SWO
PB4(NJTRST).Signal=I2S1_SDI
PB6.Signal=I2C1_SCL
PB7.Signal=I2C1_SDA
PC1.Signal=SAI4_SD_A
PC15-OSC32_OUT.GPIO_Label=DSP_CLOCKS_EN
PC15-OSC32_OUT.Signal=GPIO_Output
PC2_C.Signal=SPI2_MISO
PC3_C.Signal=SPI2_MOSI
PC9.Signal=I2S_CKIN
PD1.GPIO_Label=DSP_LEFT
PD1.Signal=GPIO_Output
PD2.GPIO_Label=DSP_RIGHT
PD2.Signal=GPIO_Output
PD3.GPIO_Label=DSP_SW
PD3.Signal=GPIO_Output
PD4.GPIO_Label=DSP_ALT
PD4.Signal=GPIO_Output
PE3.Signal=SAI1_SD_B
PE4.Signal=SAI1_FS_A
PE5.Signal=SAI1_SCK_A
PE6.Signal=SAI1_SD_A

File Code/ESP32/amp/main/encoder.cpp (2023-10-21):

#include "encoder.h"
#include <stdio.h>
#include <stdlib.h>
#include "debug.h"

Encoder::Encoder( uint8_t pin1, uint8_t pin2, bool reverse ) : mPin1( pin1 ), mPin2( pin2 ), mReverse( reverse ), mISRstate( -1 ) {
    mLastState = getState();
    mInternalDir = ENCODER_WAITING;
    mClicks = 0;

    mLevel = 0xf00000;
    mLastEmitLevel = mLevel;
}

uint8_t 
Encoder::getState() {
    uint8_t level1 = gpio_get_level( (gpio_num_t) mPin1 );
    uint8_t level2 = gpio_get_level( (gpio_num_t) mPin2 );

    return ( level1 << 1 ) | level2;
}

ENCODER_DIR 
Encoder::process() {
    ENCODER_DIR returnValue = ENCODER_NONE;
    uint8_t currentState = getState();

    if ( currentState == mLastState ) {
        return returnValue;
    }

    // forward
    // right -> 00 -> 01 -> 11 -> 10
    // left ->  00 -> 10 -> 11 -> 01
    switch( mLastState ) {
        case 0:
            // can switch to 01 or 10 
            if ( currentState == 1 ) {
                mLevel++;
            } else if ( currentState == 2 ) {        
                mLevel--;
            }
            break;
        case 1:
            // 01 can go to 11 or 00
            if ( currentState == 0 ) {
                mLevel--;
            } else if ( currentState == 3 ) {
                mLevel++;
            }
            break;
        case 2:
            // 10 can go to 11 or 00
            if ( currentState == 3 ) {
                mLevel--;
            } else if ( currentState == 0 ) {
                mLevel++;
            }        
            break;
        case 3:
             // 11 can go to 10 or 01
            if ( currentState == 2 ) {          
                mLevel++;
            } else if ( currentState == 1 ) {
                mLevel--;
            }           
            break;
    }

    mLastState = currentState;

    if ( mLevel % 4 == 0 ) {
        if ( mLevel != mLastEmitLevel ) {
            if ( mLevel > mLastEmitLevel ) {
                if ( !mReverse ) returnValue = ENCODER_FORWARD; else returnValue = ENCODER_BACKWARD;
            } else if ( mLevel < mLastEmitLevel ) {
                if ( !mReverse ) returnValue = ENCODER_BACKWARD; else returnValue = ENCODER_FORWARD;
            }
            mLastEmitLevel = mLevel;
        }
    }

    return returnValue;
}

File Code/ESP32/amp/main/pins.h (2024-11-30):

#ifndef __PINS_H__
#define __PINS_H__

#include <stdio.h>
#include <driver/gpio.h>

typedef gpio_num_t PIN;

#define PIN_BUTTON_VOLUME       GPIO_NUM_12
#define PIN_BUTTON_INPUT        GPIO_NUM_17
#define PIN_BUTTON_POWER        GPIO_NUM_25


#define PIN_LED_FRONT_POWER     GPIO_NUM_26
#define PIN_LED_FRONT_STANDBY   GPIO_NUM_27

#define PIN_RELAY               GPIO_NUM_23
#define PIN_BACKLIGHT           GPIO_NUM_2

#define PIN_DECODER_RESET       GPIO_NUM_5
#define PIN_DECODER_IRQ         GPIO_NUM_18

#define PIN_LED_ACTIVE          GPIO_NUM_14

#define PIN_CS8416_RESET        GPIO_NUM_19

#endif

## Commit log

2023-01-10 Working on I2C interface
2023-01-19 Updates for encoders
2023-01-24 Fixed issue with start up audio not working.. added bitbanging
    [main.c]
2023-09-17 Checking in AC relay
    [ACRelay.kicad_pcb, ACRelay.kicad_sch]
2023-10-03 Updating Main Project
    [ACRelay.kicad_pcb, ACRelay.kicad_sch, BindingPosts.kicad_pcb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]
2023-10-03 Adding images
    [BindingPosts.kicad_pcb]
2023-10-03 Updated ESP32
    [partitions.csv]
2023-10-03 PCB updates
2023-10-03 Updates for all readmes
    [BindingPosts.kicad_pcb, BindingPosts.kicad_sch, ChannelSelector.kicad_pcb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]
2023-10-04 Removing gerbers and backups
    [Phono Pre-amp.kicad_pcb, Phono Pre-amp.kicad_sch, SOIC DIP.kicad_pcb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]
2023-10-04 Updating file structure
    [ACRelay.kicad_pcb, ACRelay.kicad_sch, PowerSupply.kicad_pcb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]
2023-10-04 KiCAD 7 updates
    [ChannelSelector.kicad_pcb, ChannelSelector.kicad_sch, PowerAmp.kicad_pcb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]
2023-10-17 Major updates
    [ACRelay.kicad_pcb, ACRelay.kicad_sch, BindingPosts.kicad_pcb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]
2023-10-26 Dolby Working
    [DAC.kicad_pcb, DAC.kicad_sch, OpampPower.kicad_pcb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]
2023-10-27 Have some sound, doesn’t sound great though
    [ACRelay.kicad_pcb, ACRelay.kicad_sch, DAC.kicad_pcb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]
2023-10-27 Dolby mostly working
    [ACRelay.kicad_pcb, DPSU.kicad_pcb, DPSU.kicad_sch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]
2023-10-31 Added button debounce code
    [ACRelay.kicad_pcb, ACRelay.kicad_sch, BindingPosts.kicad_pcb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]
2023-11-04 More updates
    [ChannelSelector.kicad_pcb, ChannelSelector.kicad_sch, OpampPower.kicad_pcb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]
2023-11-05 Mostly working
    [ChannelSelector.kicad_pcb, ChannelSelector.kicad_sch, DAC.kicad_pcb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]
2023-11-05 Switch to I2S
2024-11-29 Updating amplifier
    [CS8416-PCB5122.kicad_pcb, CS8416-PCB5122.kicad_sch, ChannelSelector.kicad_pcb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]
2024-12-01 Adding new PCBs and new IR remote code
    [PowerAmp.kicad_pcb, PowerAmp.kicad_sch, PowerSupply.kicad_pcb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]
2024-12-08 Fixing audio issues, leave TRUNC off and at 24 bits
    [ADC.kicad_pcb, ADC.kicad_sch, ChannelSelector.kicad_pcb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]
2024-12-21 Updates to amplifer
    [ADC.kicad_pcb, ADC.kicad_sch, DAC.kicad_pcb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]
2024-12-31 Moving files
    [ADC.kicad_pcb, DAC.kicad_pcb, DAC.kicad_sch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]
2025-01-02 Replacing PeakingEQ
    [Extend.kicad_pcb, Extend.kicad_sch]
